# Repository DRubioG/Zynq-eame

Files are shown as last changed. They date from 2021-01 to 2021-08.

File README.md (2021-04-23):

# Introducción / Introduction

**[ES]** Este es el repositorio en GitHub del blog [soceame.wordpress.com](http://soceame.wordpress.com) en el que se colgará toda la información sobre cómo construir SoCs de Xilinx 

**[EN]** This is the GitHub's repository of the [soceame.wordpress.com](https://soceame.wordpress.com)'s blog where it will be uploaded all information about how to build Xilinx's SoCs

# Contenido / Content

- [Documentación/Documentation](/Documentacion): 

**[ES]** En esta carpeta se ubicarán los documentos que explican la construcción de los SoCs 

**[EN]** In this folder will be placed the documents which explaining how to build the SoCs

- [Zynq-eame_0](/Zynq-eame_0): ❗ No terminada / Unfinished ❗

**[ES]** Esta carpeta contiene los esquemáticos de la Zynq-eame_0 en pdf y en KiCad.

Esta placa está construida a partir de un XC7Z010-CLG400.

**[EN]** This folder contains the Zynq-eame_0' schematics in pdf and in KiCad.

This board is built from a XC7Z010-CLG400.

- [Zynq-eame_UltraScale_0](/Zynq-eame_UltraScale_0): ❗ Inicio / Started ❗

**[ES]** Esta carpeta contiene los esquemáticos de la Zynq-eame_UltraScale_0 en pdf y en KiCad.

Esta placa está construida a partir de un XCZU2CG-SBVA484.

**[EN]** This folder contains the Zynq-eame_UltraScale_0' schematics in pdf and in KiCad.

This board is built from a XCZU2CG-SBVA484.

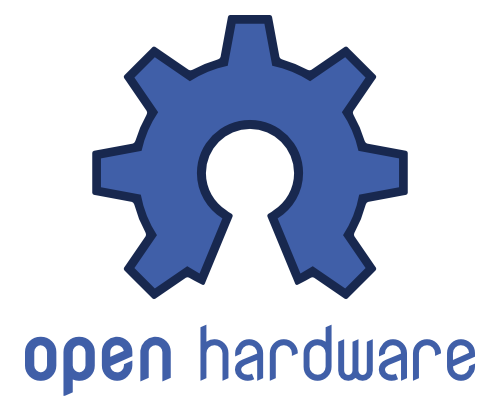
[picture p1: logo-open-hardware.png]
Open Hardware


**[ES]** Estos son proyectos Open Hardware 

**[EN]** These are Open Hardware projects

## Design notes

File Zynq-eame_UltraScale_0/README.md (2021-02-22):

# Zynq-eame UltraScale  0

## Descripción / Description

**[ES]** La Zynq-eame UltraScale 0 es un placa basada en un XCZU2CG de Xilinx de la familia de las Zynq UltraScale+.
Esta placa consta de:
- 1Gb de memoria ram DDR4 (512Mbx2)
- Salida HDMI 
- SD 3.0
- Comunicación USB
- USB-JTAG 
- Quad-SPI Flash Memory
- 5 switches programables (activos a nivel bajo)
- 5 botones programables (activos a nivel alto)
- 5 leds programable (activos a nivel alto)
- 3 bancos de pines: uno de 48 pines y otro de 26 pines programables por Hardware y uno de 38 pines de tipo MIO
- 2 bancos de pines de alimentación
- Encendido por switch
- Alimentación a 5V

**[EN]** Zynq-eame 0 is a XCZU2CG based board from the Zynq UltraScale+'s family from Xilinx.
This board consist of:
- 1Gb of DDR4 ram memory (512Mbx2)
- HDMI output
- SD 3.0
- USB communication
- USB-JTAG
- Quad-SPI Flash Memory
- 5 programmable switchs (low level active)
- 5 programmable buttons (high level active)
- 5 programmable led (high level active)
- 3 banks of pins: one with 48 pins and other with 26 pins hardware programmable and one with 38 MIO pins 
- 2 supply banks
- Turn-on by switch
- 5V of supply

## Esquemático / Schematic
👉 [Zynq-eame 0](Zynq-eame_UltraScale_0.pdf)

## Vivado
**[ES]** En este carpeta se ubicarán los documentos que harán la Zynq-eame 0 una [placa de Vivado](Vivado)

**[EN]** In this folder it will be placed the documents that will make Zynq-eame 0 a [Vivado's board](Vivado)

## Proyecto / Project
👉[Proyecto/Project](KiCad)

## Datasheet
👉[Datasheet](Datasheet)

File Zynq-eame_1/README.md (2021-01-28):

# Zynq-eame 0

## Descripción / Description

**[ES]** La Zynq-eame 0 es un placa basada en un XC7Z010 de Xilinx de la familia de las Zynq-7000.
Esta placa consta de:
- 512Mb de memoria ram DDR3
- Salida HDMI 
- SD
- Comunicación USB
- USB-JTAG 
- Quad-SPI Flash Memory
- 5 switches programables (activos a nivel bajo)
- 5 botones programables (activos a nivel alto)
- 5 leds programable (activos a nivel alto)
- 3 bancos de pines: uno de 48 pines y otro de 26 pines programables por Hardware y uno de 38 pines de tipo MIO
- 2 bancos de pines de alimentación
- Encendido por switch
- Alimentación a 5V

**[EN]** Zynq-eame 0 is a XC7Z010 based board from the Zynq-7000's family from Xilinx.
This board consist of:
- 512Mb of DDR3 ram memory
- HDMI output
- SD
- USB communication
- USB-JTAG
- Quad-SPI Flash Memory
- 5 programmable switchs (low level active)
- 5 programmable buttons (high level active)
- 5 programmable led (high level active)
- 3 banks of pins: one with 48 pins and other with 26 pins hardware programmable and one with 38 MIO pins 
- 2 supply banks
- Turn-on by switch
- 5V of supply

## Esquemático / Schematic
👉 [Zynq-eame 0](Zynq-eame_0.pdf)

## Vivado
**[ES]** En este carpeta se ubicarán los documentos que harán la Zynq-eame 0 una [placa de Vivado](Vivado)

**[EN]** In this folder it will be placed the documents that will make Zynq-eame 0 a [Vivado's board](Vivado)

## Proyecto / Project
👉[Proyecto/Project](KiCad)

## Datasheet
👉[Datasheet](Datasheets)

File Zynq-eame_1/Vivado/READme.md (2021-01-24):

# Descripción / Description 
[ES] En este carpeta se ubicarán los documentos que harán la Zynq-eame 0 una placa de Vivado

[EN] In this folder it will be placed the documents that will make Zynq-eame 0 a Vivado's board

## Documentos/Documents

- [Zynq-eame_XDC.xdc](Zynq-eame_XDC.xdc)

**[ES]** Este es el fichero XDC de la Zynq-eame 0

**[EN]** This is the Zynq-eame 0's XDC file

- [Zynq-eame](Zynq-eame)

**[ES]** Esta carpeta contiene todos los ficheros que hacen la placa reconocible en Vivado. Pegar en el directorio: *..\Xilinx\Vivado\<version de Vivado>\data\boards\board_files* . Con esta carpeta se pueden usar los bloques IP como AXI_GPIO, Microblaze_msc, iomodule y clock_wiz con los pines de la Zynq-eame.

**[EN]** This folder contains every file that makes reconocible the board in Vivado. Paste in the path: *..\Xilinx\Vivado\<version of Vivado>\data\boards\board_files*  . With this folder you can use  IP blocks as AXI_GPIO, Microblaze_msc, iomodule and closk_wiz with the pins of Zynq-eame.

- [Zynq-eame.tcl](Zynq-eame.tcl)

**[ES]** Pega este archivo en el siguiente directorio: *..\Xilinx\Vivado\<version de vivado>\data\ip\xilinx\processing_system7_v5_5\preset* . Este fichero es la preconfiguración de la Zynq-eame 0 con toda la configuración del Zynq. **Este archivo lo carga la configuración anterior**

**[EN]** Paste this file in this path: *..\Xilinx\Vivado\<version of vivado>\data\ip\xilinx\processing_system7_v5_5\preset* . This file is the preconfiguration of the Zynq-eame 0 with all configuration of the Zynq. **This file is precharged by the previous configuration**

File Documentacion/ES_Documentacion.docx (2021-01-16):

XD

Soc-eame | soceame.wordpress.com

diseño de un SoC basado en Zynq-7000

# Introducción

En este documento se detallará de la forma más extensa y detallada la forma de crear un SoC basado en un Zynq-7000 de Xilinx, detallando dónde encontrar los documentos y la información necesaria para la construcción de uno, además también se incluye cómo se configura en Vivado para que reconozca la nueva placa como una placa preconfigurada.

Al final del documento se incluye un ejemplo de cómo construir un SoC basado en un núcleo xc7z010-clg400 [este ejemplo se corresponde con la construcción de una Zynq-eame 0]

Este documento ha sido desarrollado por el blog https://soceame.wordpress.com/ Para cualquier aporte o mejora soceame@gmail.com.

Y para cualquier aportación económica para futuros proyectos http://paypal.me/soceame

# ¿Qué es un SoC?

Un SoC es la combinación de la electrónica de una FPGA con un microprocesador embebido en un chip.

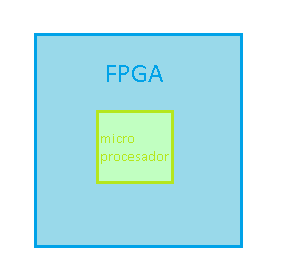
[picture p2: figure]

## Diferencia entre un SoC, un microcontrolador y una FPGA

| SoC | Microcontrolador | FPGA
Microprocesador | ✔ | ✔ | ❌ (pero se le puede configurar un soft-core)*
Hardware programable | ✔ | ❌ | ✔
Lenguajes de programación | HDLs y lenguajes de medio-bajo nivel | Lenguajes de bajo-medio nivel: C, C++ | HDLs**: VHDL, Verilog
Precio del chip | Medio-alto (de la familia Zynq-7000, de 35€ hasta 20.000€) | Bajo | Bajo-Medio

* Un soft-core en un microprocesador creado usando las puertas lógicas internas del chip

** Los lenguajes HDL son “lenguajes de descripción de hardware” por lo que con ellos se puede programar el hardware

# Comienzo

Lo primero que hay que hacer para construir una Zynq-7000 es saber los tipos de Zynq que hay.

Para ello se recurre al Product Selection Guide (https://www.xilinx.com/support/documentation/selection-guides/zynq-7000-product-selection-guide.pdf) de Xilinx para la Zynq-7000. En él se encuentra una tabla como la siguiente en la que se desglosa qué contienen internamente los diferentes tipos de Zynq.

Como se puede ver hay una parte de la familia que solo tiene un microprocesador, mientras el resto tiene dos microprocesadores dentro con diferentes velocidades.

Otro factor condicionante a la hora de elegir un chip son las puertas lógicas internas, para ello es conveniente elegir más puertas lógicas de las que se van a necesitar para evitar problemas de falta de celdas.

## Número de pines

Para construir un SoC también hay que tener en cuenta el número de pines que va a tener la salida para poder crear el símbolo en el programa de diseño. En el mismo documento de antes existe la tabla que determina los pines que puede tener cada chip

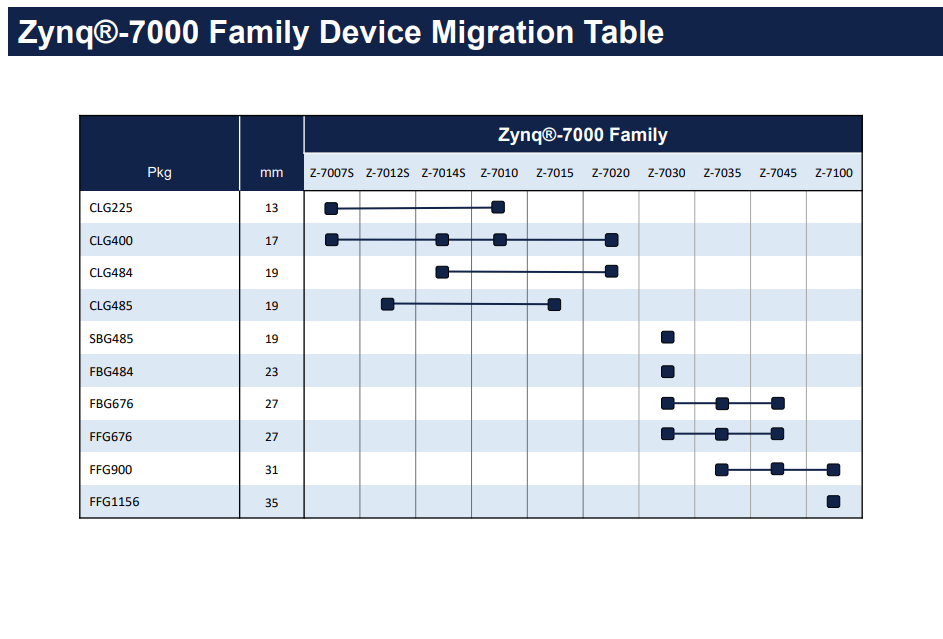
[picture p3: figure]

Según la tabla si se quiere construir un SoC con el Z-7007S se puede elegir el encapsulado CLG225 y el CLG400, se diferencian en que el encapsulado CLG225 tiene 225 pines en una matriz de 15 filas x 15 columnas, y el CLG400 igual pero con 400 pines.

A partir de ahora se va a documentar la construcción de SoC.

Para una mayor documentación sobre la familia Zynq-7000 👇

https://www.xilinx.com/support/documentation/data_sheets/ds190-Zynq-7000-Overview.pdf

# Pinout

Para localizar la configuración del número y el tipo de pines se tiene que recurrir al documento Packaging and Pinout (https://www.xilinx.com/support/documentation/user_guides/ug865-Zynq-7000-Pkg-Pinout.pdf).

En este documento figuran los nombres de los pines, la definición de los pines y las huellas de los diferentes encapsulados.

## Nombres de los pines

❗❗ Esto es extremadamente importante porque NO figuran implícitamente en el documento, figuran como un enlace a otros documentos❗❗

En la página 27 del documento figuran los enlaces a los respectivos documentos en función del chip y del encapsulado

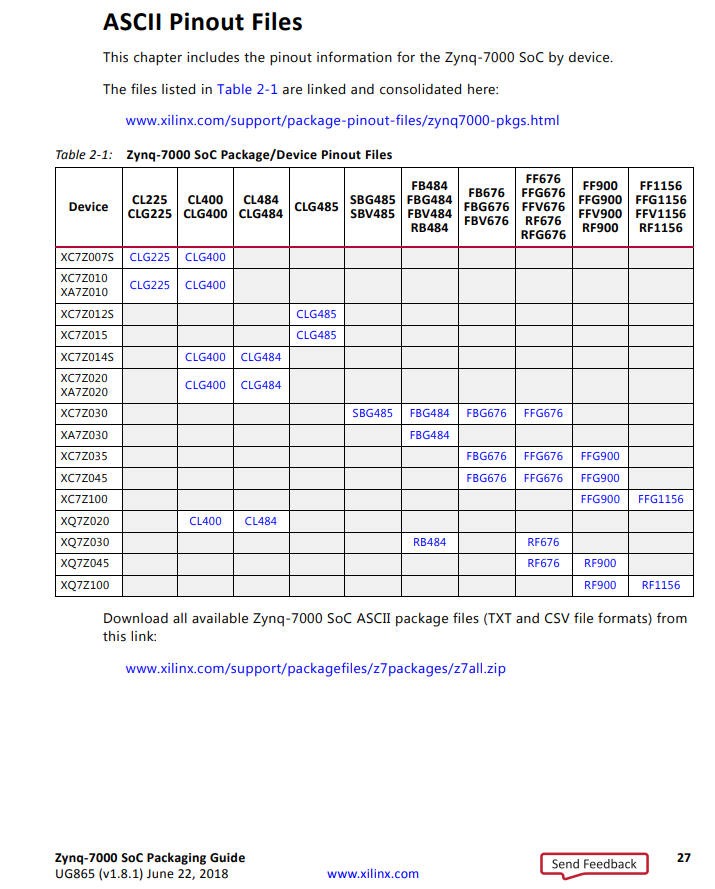
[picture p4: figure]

Estos enlaces llevan a páginas como la siguiente, en la que los pines están clasificados en bancos.

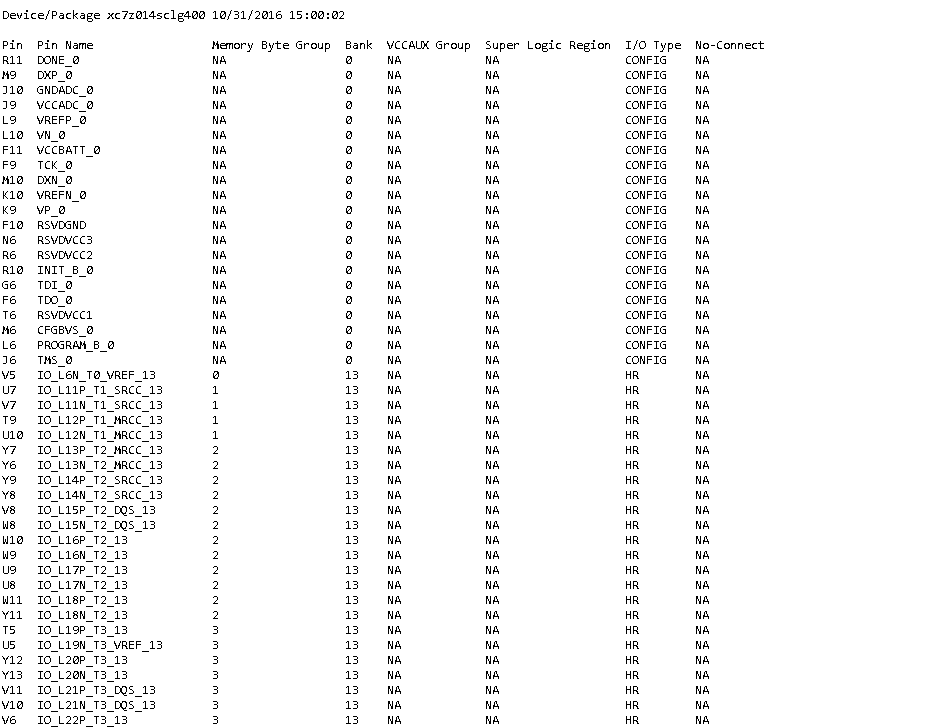
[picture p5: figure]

Los campos importantes son:

En la primera columna figura el número del pin*(este número es importante porque luego se utilizará para generar el XDC).

La segunda columna se corresponde con el nombre del pin, este nombre es importante para saber cuales son los bits de mayor o menor peso o la dedicación que tiene

La cuarta columna se corresponde con el banco de pines al que pertenecen los pines( esta división por bancos se puede utilizar para crear el símbolo del componente)

La octava columna se corresponde con el tipo de pin, CONFIG para configuración, HR para configurar por hardware, MIO para pines de tipo MIO, DDR pines para la memoria Ram y NA para alimentaciones y masas.

*el número del pin se corresponde con la numeración de los encapsulados en forma de matriz cuadrada, las columnas están ordenadas por números, y las filas por letras. Por ejemplo, el formato CLG25 tiene 5 filas y 5 columnas, por lo que la primera fila empieza por el pin A1 y acaba por el pin A5, la siguiente fila por el B1 – B5, y así hasta la última fila, E1-E5.

## Definición de los pines.

De la página 12 en adelante del documento figura la definición de los pines.

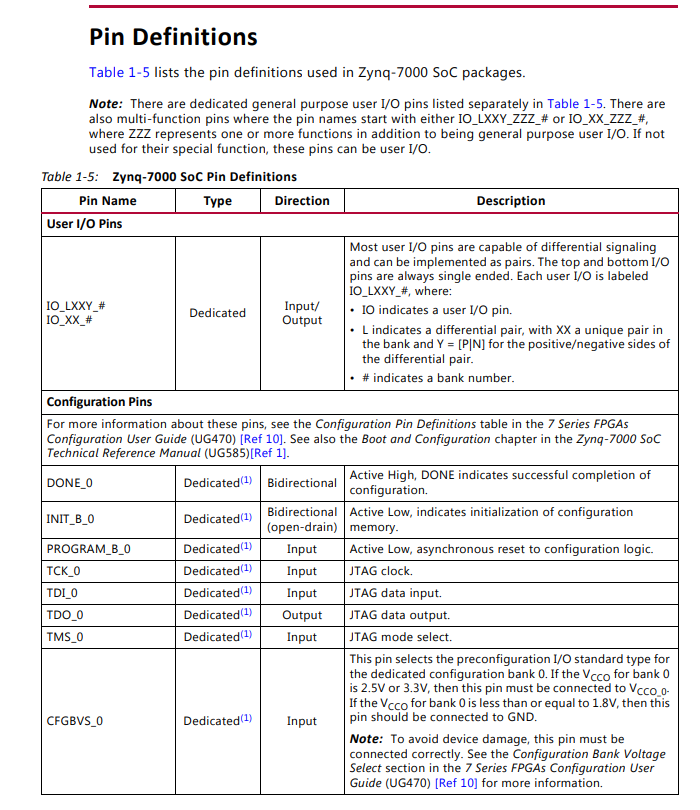
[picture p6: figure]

# Huellas de los encapsulados

Al final del documento figuran las estructuras de los pines en chip y las huellas

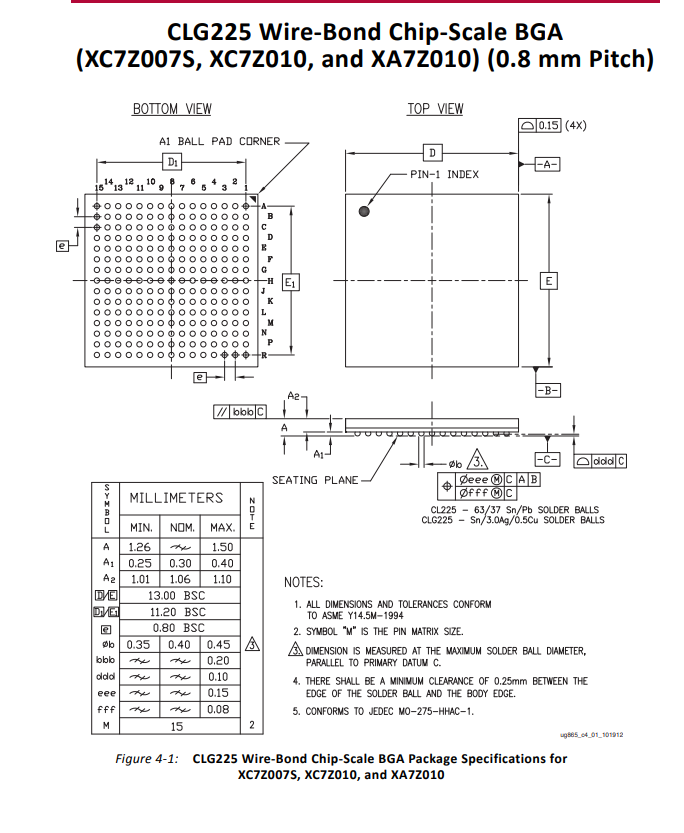
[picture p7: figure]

**Estas huellas con del chip que se va a soldar, NO las huellas que se tienen que hacer en la PCB, estas últimas son las simétricas con el eje vertical. La huella que se tiene que fabricar en la PCB tiene que tener el pin A1 en la parte superior izquierda.

# Ejemplo

## Introducción

Debido a que explicar cómo construir un SoC es complejo ahora se va a explicar con un ejemplo.

Se va a construir una Zynq-eame 0 que está basada en un XC7Z010-CLG400.

Zynq-eame es una placa creada para Open Hardware por el blog soceame.wordpress.com utilizando KiCad(software Open Source)

## Documentación

Un XC7Z010 consta de las características que nos da la tabla.

## Pinout

Para el Pinout se recurre a la tabla

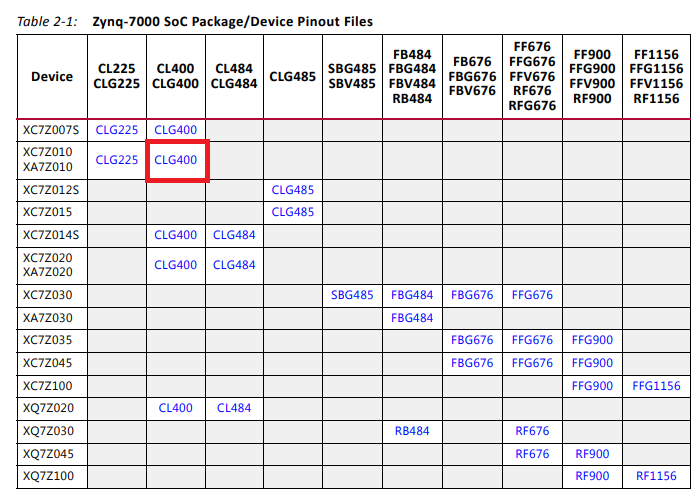
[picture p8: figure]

Que nos lleva a la página (https://www.xilinx.com/support/packagefiles/z7packages/xc7z010clg400pkg.txt) con los pines se parados por bancos. A partir de esta separación por pines se pueden hacer los símbolos en el programa de diseño de PCBs.

## Símbolo.

Para hacer los símbolos se va a recurrir a la separación por bancos de la que se ha hablado anteriormente.

- Bank 0

Este banco está reservado para las referencias, por ejemplo, la tensión del ADC o la referencia de temperatura

  - Pinout
  - Símbolo

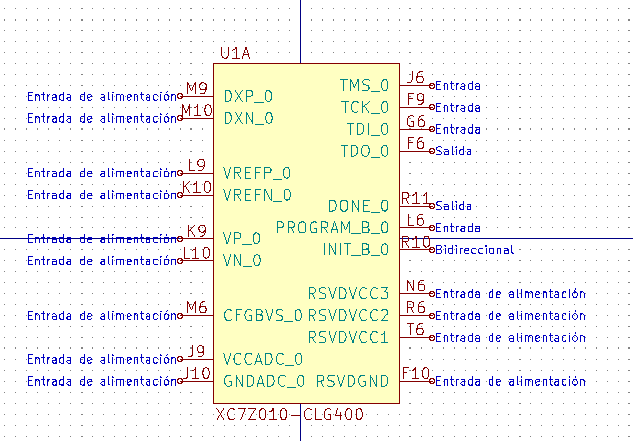
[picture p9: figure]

- Unconnected

Estos pines en el XC7Z010 no están conectados pero en otros formatos sí que lo pueden estar

  - Pinout
  - Símbolo

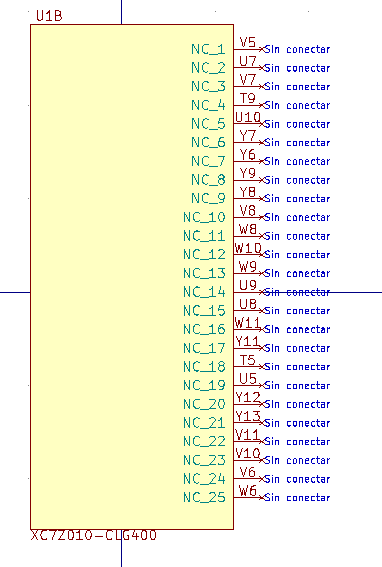
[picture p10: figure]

- Bank 34

Estos pines son configurables como entrada y salida por hardware. Entre los pines de este banco hay pines que pueden tener otro tipo de configuración.

  - Pinout
  - Símbolo

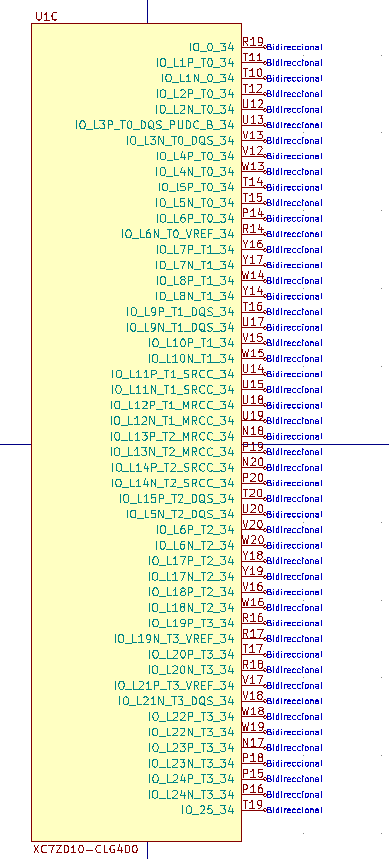
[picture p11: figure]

- Bank 35

Estos pines son configurables como entrada y salida por hardware. Entre los pines de este banco hay pines que pueden tener otro tipo de configuración.

  - Pinout
  - Símbolo

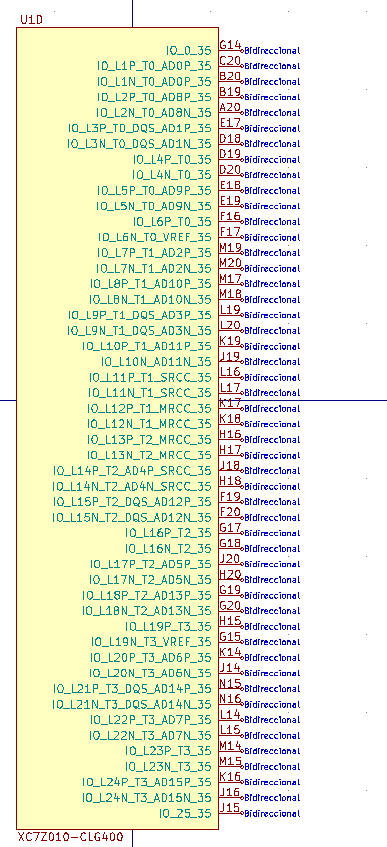
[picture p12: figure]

- Bank 500 & 501

Estos bancos están destinados para los pines de tipo MIO (Multiple IO)

  - Pinout
  - Símbolo

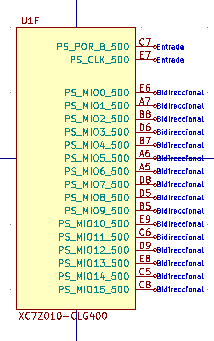
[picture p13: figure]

- Bank 502

Este banco está destinado únicamente a la memoria Ram, 15 bits de Address y 32 bits de Datos

  - Pinout

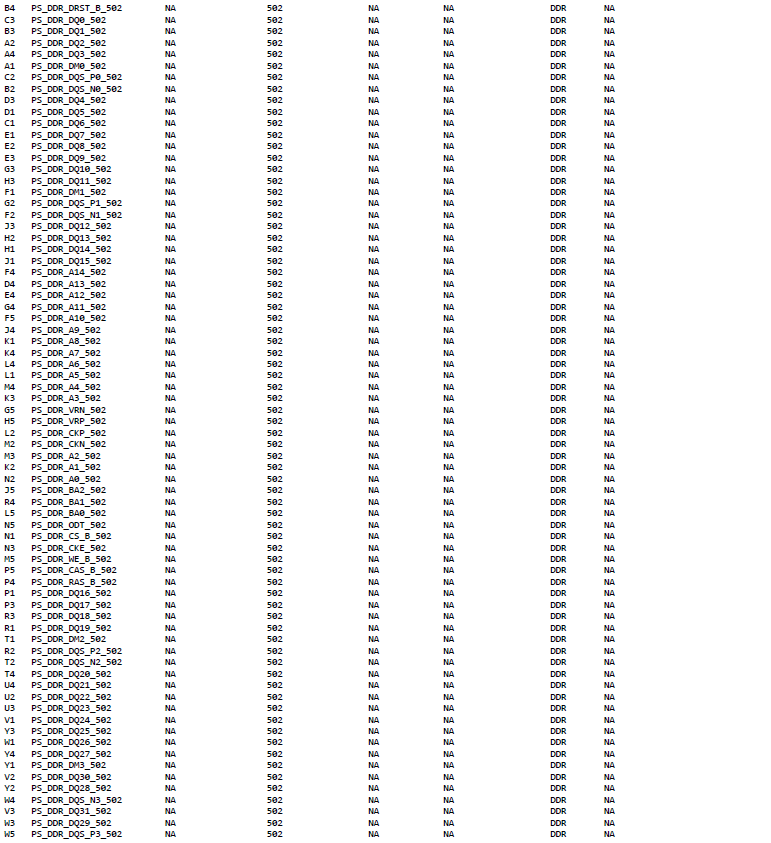
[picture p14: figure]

👆estos dos últimos pines están al final del documento

  - Símbolo
- Bank GND

Este banco está destinado únicamente a masas

  - Pinout

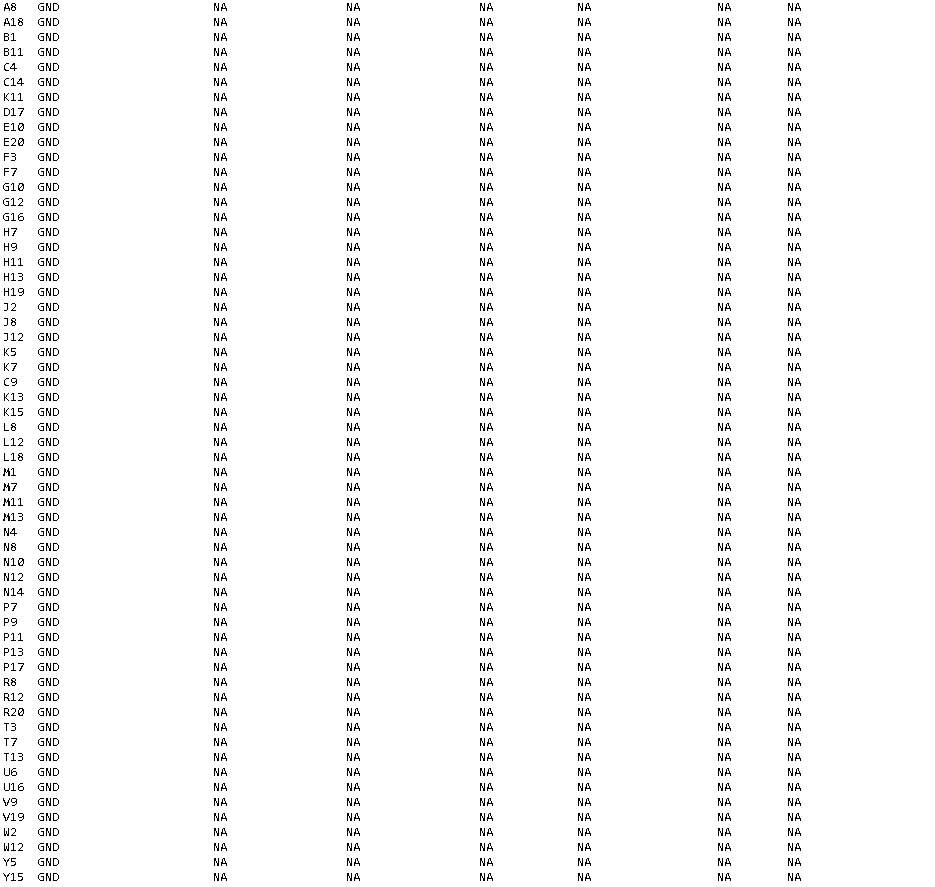
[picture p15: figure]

  - Símbolo
- Bank VCC

Este banco está destinado únicamente a las diferentes alimentaciones del sistema.

  - Pinout

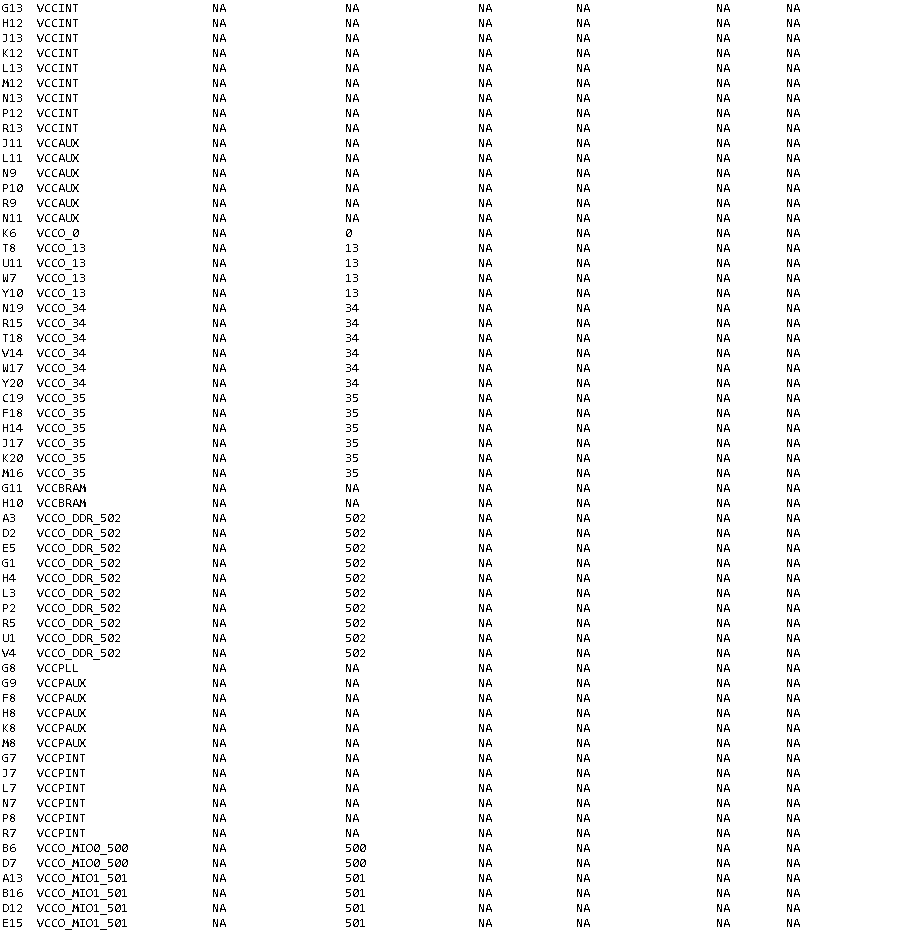
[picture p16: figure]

  - Símbolo

# Conexión

Para la conexión de va a desglosar para cada pin cómo debería estar conectado.

- Bank 0

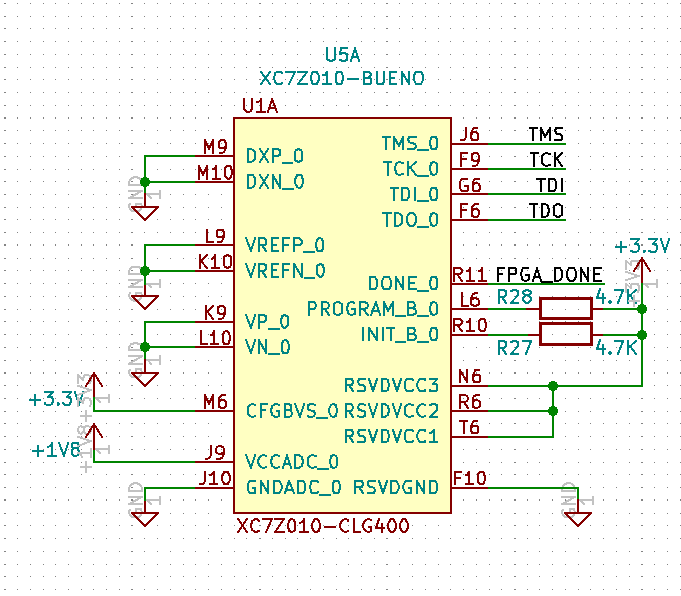
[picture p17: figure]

DXP_0 y DXN_0 a masa porque no se va a conectar un diodo para el sensado de la temperatura.

VREFP_0, VREFN_0, VP_0 y VN_0 a masa porque no se va a conectar un ADC.

CFBVS_0 a 3.3V para preconfigurar los pines

VCCADC_0 es la tensión de alimentación del XADC, tiene que estar a 1.8V

GNDADC_0 es la masa del XADC, se conecta a la masa general porque no se va a utilizar el ADC.

RSVDVCC[3:1] tienen que ir a la tensión Vcco_0, en el caso de la Zynq-eame 0 a 3V3.

INIT_B_0 indica la inicialización de la configuración de la memoria, se activa a nivel bajo.

PROGRAM_B_0 reset asíncrono activo a nivel bajo. Se conecta a 3V3 porque no se resetea la placa.

DONE_0 indica que la configuración se ha completado, activo a nivel alto. En la Zynq-eame se conecta a un diodo LED para indicar si se ha cargado la placa.

TMS_0, TCK_0, TDI_0 y TDO_0 son los pines del JTAG, estos pines pueden ir a un cable depurador o a un chip que permita cargar el programa por USB. En la Zynq-eame se utiliza el FT2232H, se necesita de una EEPROM y un oscilador de 12MHz pero elimina la necesidad de un cable depurador.

- Bank Unconnected
- Bank 34

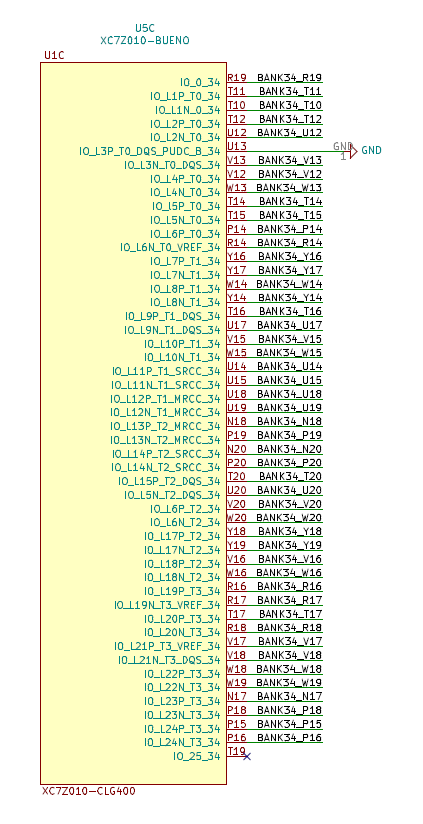
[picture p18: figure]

Todos lo pines IO son pines que se pueden configurar por Hardware y algunos de ellos pueden adquirir otras configuraciones.

Los pines IO_Ln[P/N] son pines diferenciales utilizados por el XADC.

El pin PUBC_B es un pin que activa las resistencias de pull-up del sistema después del arranque y durante la configuración. Activa a nivel bajo, tiene que ir directamente a GND o a VCCO_34

SRCC y MRCC estos pines permiten que un reloj funcione en varias regiones(MRCC) o en solo una (SRCC). Estos pines tienen interés en las FPGAs para conectar el oscilador de la frecuencia a ellas. La Zynq-eame no lleva conectado un reloj a un pin MRCC por eso no puede ser utilizada como una FPGA sin activar el reloj interno del Zynq.

En la Zynq-eame 0 todo el banco va a pines de salida, menos el pin PUBC_B que va a masa y el pin T19 que no se conecta porque no tiene un pin de salida.

- Bank 35

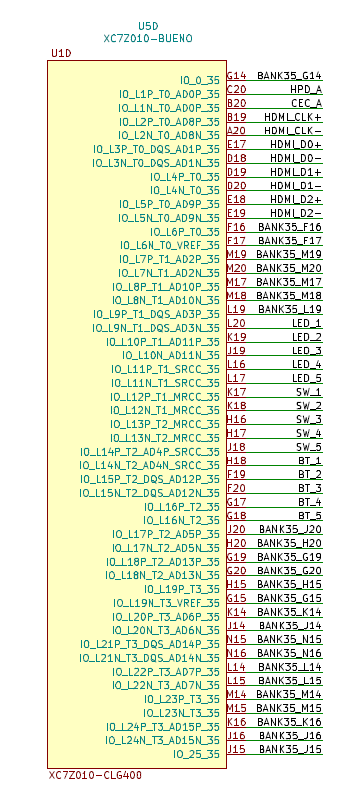
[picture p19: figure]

Pasa igual que en el banco 34, hay pines con múltiples funciones.

Este banco se utiliza entero.

Se conectan los pines HDMI a los pines elegidos, éstos van a un TPD12S016 que va conectado al HDMI hembra

Les pines que se van a utilizar para los leds llevan un transistor para funcionar.

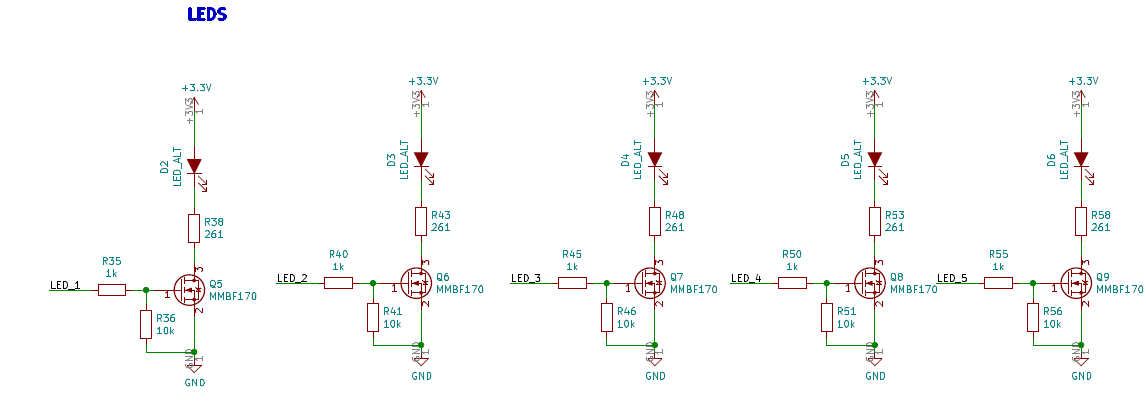
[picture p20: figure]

Los pines que van a los switches son activos a nivel bajo.

Los pines que van a los botones son activos a nivel alto.

Y el resto de los pines va a pines de salida.

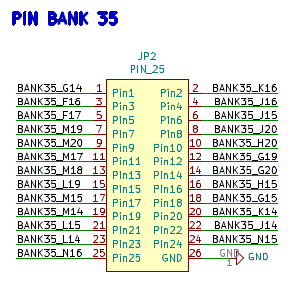
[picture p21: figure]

- Bank 500 & 501

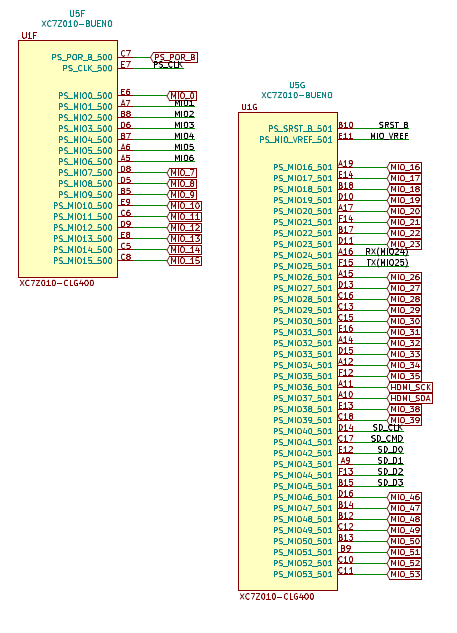
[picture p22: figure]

Banco 500:

PS_POR_B utiliza para mantener un reset al arranque del sistema, el sistema que se utiliza es un supervisor que mantiene el sistema reseteaso. Para eso se utiliza el dispositivo que propone Xilinx (https://www.xilinx.com/Attachment/AR65240_-_Example_PS_POR_B_Supervisor_Circuit.pdf), un TPS3106K33DBV, que mantiene el reset durante 130ms[según el datasheet (https://www.ti.com/lit/ds/symlink/tps3106.pdf?ts=1610541218328)].

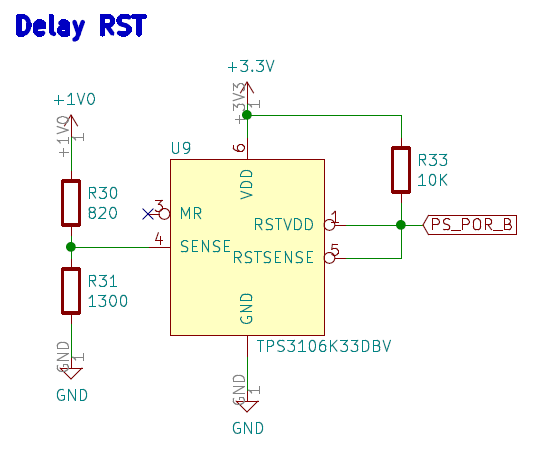
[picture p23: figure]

PS_CLK este es el reloj del sistema y tiene que ir conectado a un oscilador entre 30 y 60MHz, en la Zynq-eame se conecta a 33.333MHz.

Los pines MIO se utilizan para pines de comunicación multiplexada.

Por eso la multiplexación de los pines 1 al 6 es la de una QUAD-SPI FLASH MEMORY

El resto de pines va a pines de salida con el resto de pines del bank MIO 501

Bank 501:

PS_SRST este pin fuerza el reseteo del sistema, activo a nivel bajo. En una Zynq-eame se conecta a un pulsador.

MIO_VREF proporciona de una tensión de referencia para RGMII (Fast Ethernet) si no se usa se puede dejar al aire. Si se conecta una interfaz RGMII se tiene que usar un divisor de tensión de 1/2, por lo que si la interfaz es de 1.8V a la entrada tiene que haber 0.9V. La Zynq-eame 0 no tiene conexión a Fast Ethernet por lo que se deja al aire.

Lo pines mio 24 y 25 son pines MIO que tienen la posibilidad de configurar la UART. Estos pines son lo que se usan para la comunicación USB.

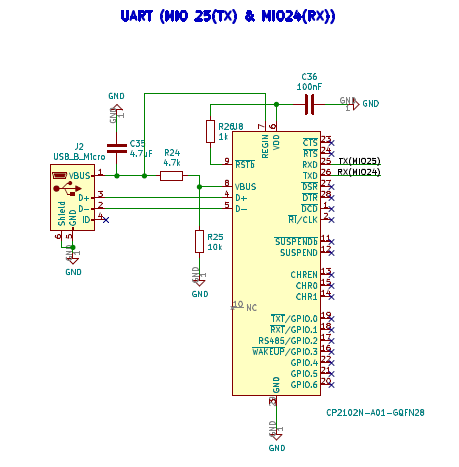
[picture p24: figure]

Los pines 40-45 son pines que permiten la conexión de una memoria SD.

El resto de los pines va conectado a pines externos

La referencia para la conexión de los pines MIO es la siguiente tabla.

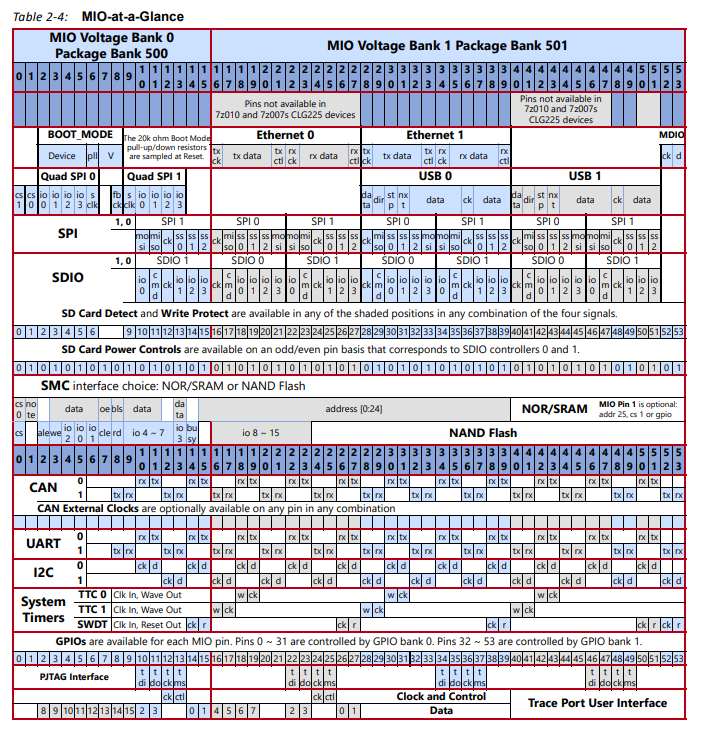
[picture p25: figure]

2 soceame.wordpress.com

Diseño de un SoC basado en una Zynq-7000

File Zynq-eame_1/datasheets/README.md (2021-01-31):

# Datasheets

## Zynq-7000
[XC7Z020 pinout](XC7Z020-CLG400_pinout.pdf)

[Zynq-7000 pinout](ug865-Zynq-7000-Pkg-Pinout.pdf)

## DDR
[Ram memory](MT41K256M16HA-125_E.pdf)

# Quad-SPI Flash Memory
[S25FL128S](S25FL128S.pdf)

## RST delay
[Xilinx example](AR65240_-_Example_PS_POR_B_Supervisor_Circuit.pdf)

[TPS3106](tps3106.pdf)

## Oscillator
[ASE-33.333MHz-LC-T](ASE-33.333MHz-LC-T.pdf)

## DC-DC 
[DC-DC](tps563201.pdf)

## HDMI 
[HDMI](tpd12s016.pdf)

## USB-JTAG
[FT2232H](DS_FT2232H.pdf)

[EEPROM](96C46.pdf)

## USB COMM
[USB COMM](an976-cp2102-3-4-9-to-cp2102n-porting-guide.pdf)

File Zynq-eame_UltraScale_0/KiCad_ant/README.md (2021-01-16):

# FPGA_propia
 En este repositorio se subirán los ficheros que permitirán crear una FPGA basada en Zynq-7000

Todo el desarrollo está hecho con KiCad (software libre) para que cualquiera pueda replicarla o mejorarla a su gusto con los ficheros que se van a publicar

## Libreria
El fichero tiene una librería llamada 'Zynq-7000' en la que está el symbol de un XC7Z010 del cual se implementará la versión CLG400 (400 pines en formato de soldadura BGA) 
## XC7Z010-BUENO
El símbolo consta de 9 partes, de las que se va a describir su selección a continuación
### - _Símbolo A_
diseno_A

En este símbolo se reflejan los pines de referencia, además de los pines de depuración TMS, TCK, TDI y TDO. Estos pines pueden necesitar de un cable depurar para cargar el programa o de un USB OTG, que permita evitar tener que usar un cable depurador.

### - _Símbolo B_
diseno_B

En este símbolo se reflejan los pines que no tienen conexión

### - _Símbolo c_
diseno_C

En este símbolo se reflejan los pines de entrada/salida que se podrán configurar como se quiera

### - _Símbolo D_
diseno_D

En este símbolo se reflejan los pines de entrada/salida que se podrán configurar como se quiera

### - _Símbolo E_
diseno_E

En este símbolo se reflejan los pines que van a ir a la/las memoria ram. A los pines de la ram se pueden unir varias memorias para aumentar su tamaño.

### - _Símbolo F_
diseno_F

En este símbolo se reflejan los pines MIO

### - _Símbolo G_
diseno_G

En este símbolo se reflejan los pines MIO continuación de los anteriores

### - _Símbolo H_
diseno_F

En este símbolo se reflejan las alimentaciones de cada parte del integrado. Hay que tener en cuenta que cada parte tiene una alimentación distinta, la VCCO_BRAM y los VCCO_PINT de 1V, los VCCO_MIO 3.3V, los VCCO_DDR de 1.35V y los VCCAUX y los VCCPAUX de 1.8V

### - _Símbolo I_
diseno_I

En este símbolo se reflejan las masas de todo el integrado. Todas las masas van unidas a mismo punto.

### - *Formato del integrado*
CLG400

En esta imagen se refleja como es el integrado CLG400 de 400 pines(20x20) para BGA

*** Toda la documentación del frabicante se puede obtener del siguiente enlace: ***
Documentación para el empaquetado: https://www.xilinx.com/support/documentation/user_guides/ug865-Zynq-7000-Pkg-Pinout.pdf
Documentación de los pines: https://www.xilinx.com/support/packagefiles/z7packages/xc7z010clg400pkg.txt

## Memoria RAM
Para la memoria ram se utiliza una MT4K256M16TW-107:P
### Datasheet
http://www.farnell.com/datasheets/3151560.pdf
### Símbolo
El símbolo utilizado es el siguiente
Memoria Ram
### Huella
La huella de la memoria ram consta de una matriz de 6x16 que está fragmetada en dos partes separadas por una zona en la que van 3 columnas de pines vacías.
Huella Memoria Ram

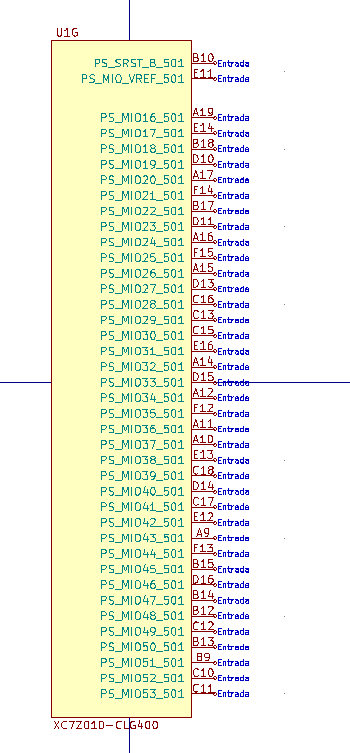
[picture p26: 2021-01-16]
Zynq-eame_1/KiCad/imagenes/XC7Z010-U1G.PNG

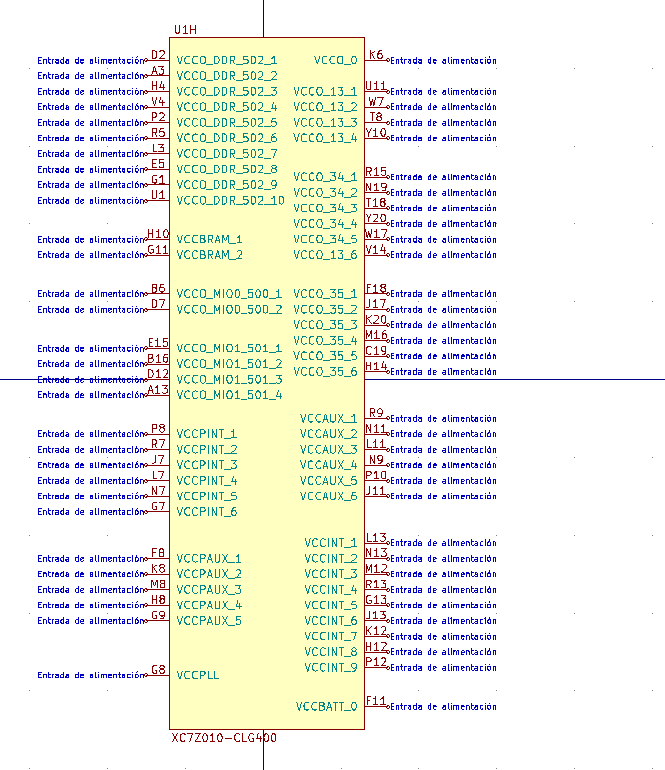
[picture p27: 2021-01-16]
Zynq-eame_1/KiCad/imagenes/XC7Z010-U1H.PNG

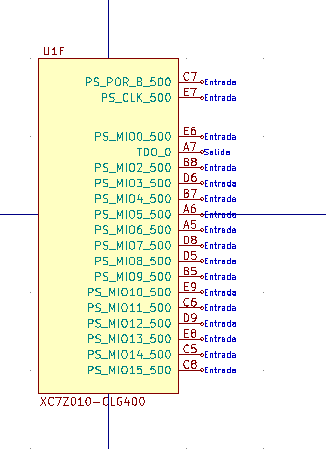
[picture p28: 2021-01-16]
Zynq-eame_1/KiCad/imagenes/XC7Z010-U1F.PNG

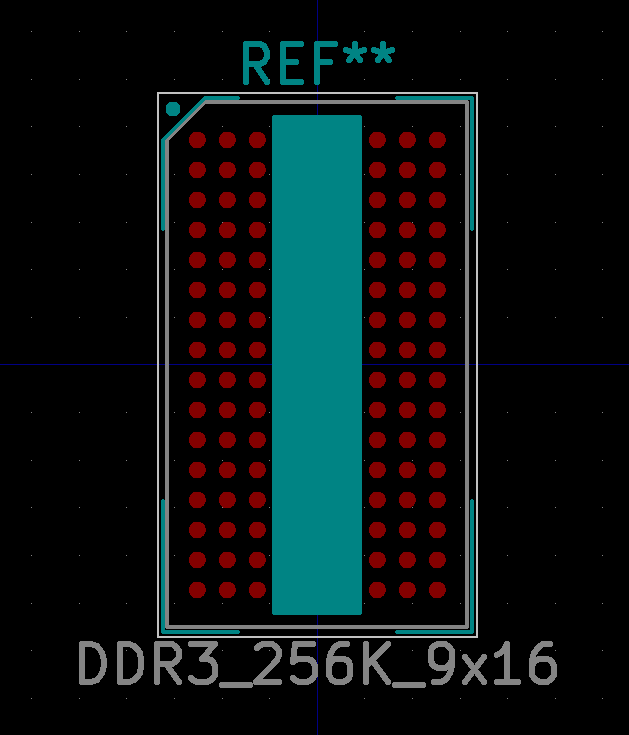
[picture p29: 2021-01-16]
Zynq-eame_1/KiCad/imagenes/TPS563201_huella.PNG

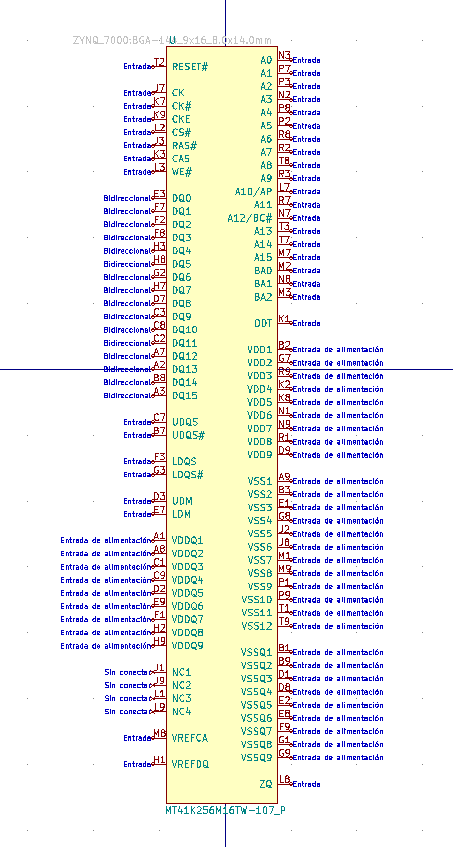
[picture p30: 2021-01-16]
Zynq-eame_1/KiCad/imagenes/TPS563201.PNG

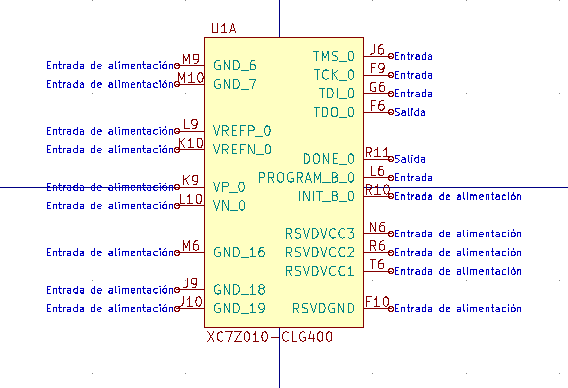
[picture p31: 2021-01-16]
Zynq-eame_1/KiCad/imagenes/XC7Z010-U1A.PNG

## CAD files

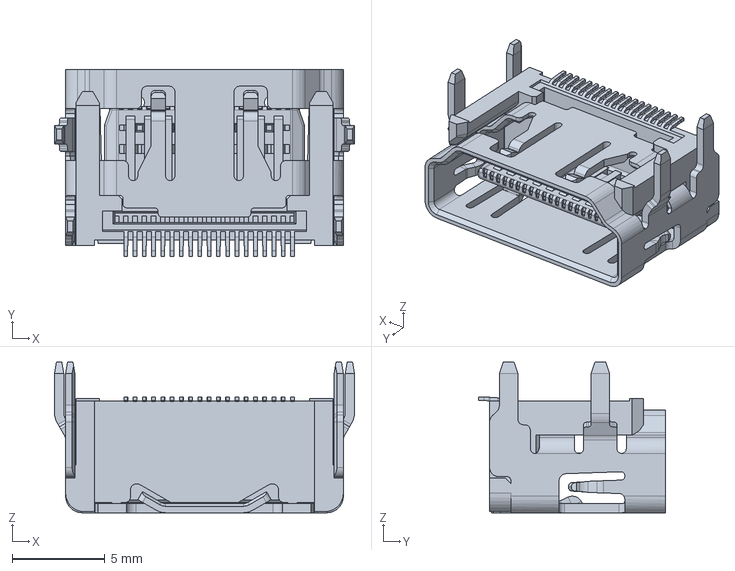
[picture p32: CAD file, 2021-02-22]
Zynq-eame_0/KiCad/10029449-111RLF.stp
16.2 x 10.1 x 8.13 mm

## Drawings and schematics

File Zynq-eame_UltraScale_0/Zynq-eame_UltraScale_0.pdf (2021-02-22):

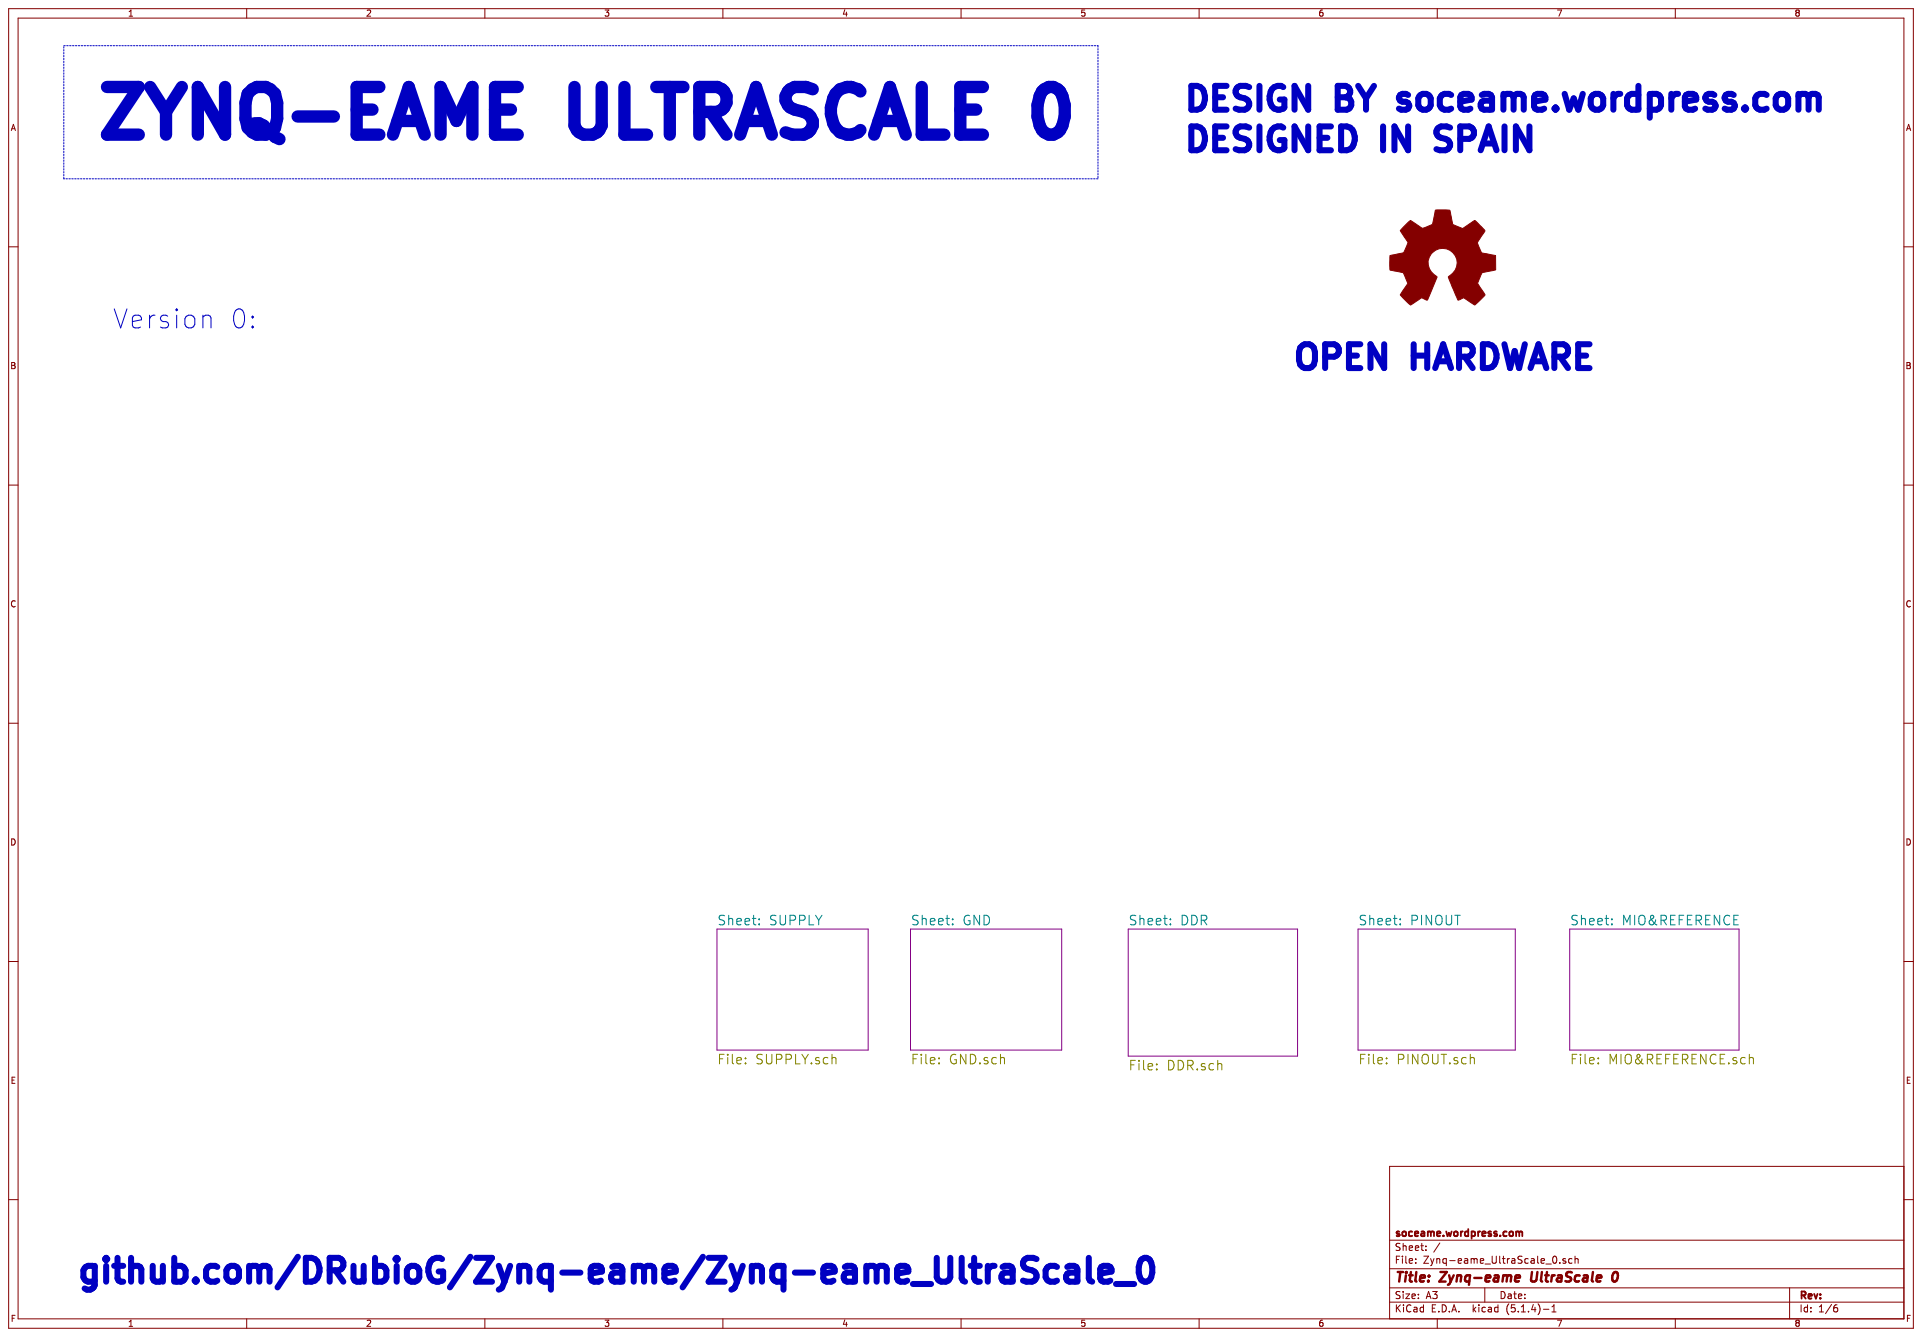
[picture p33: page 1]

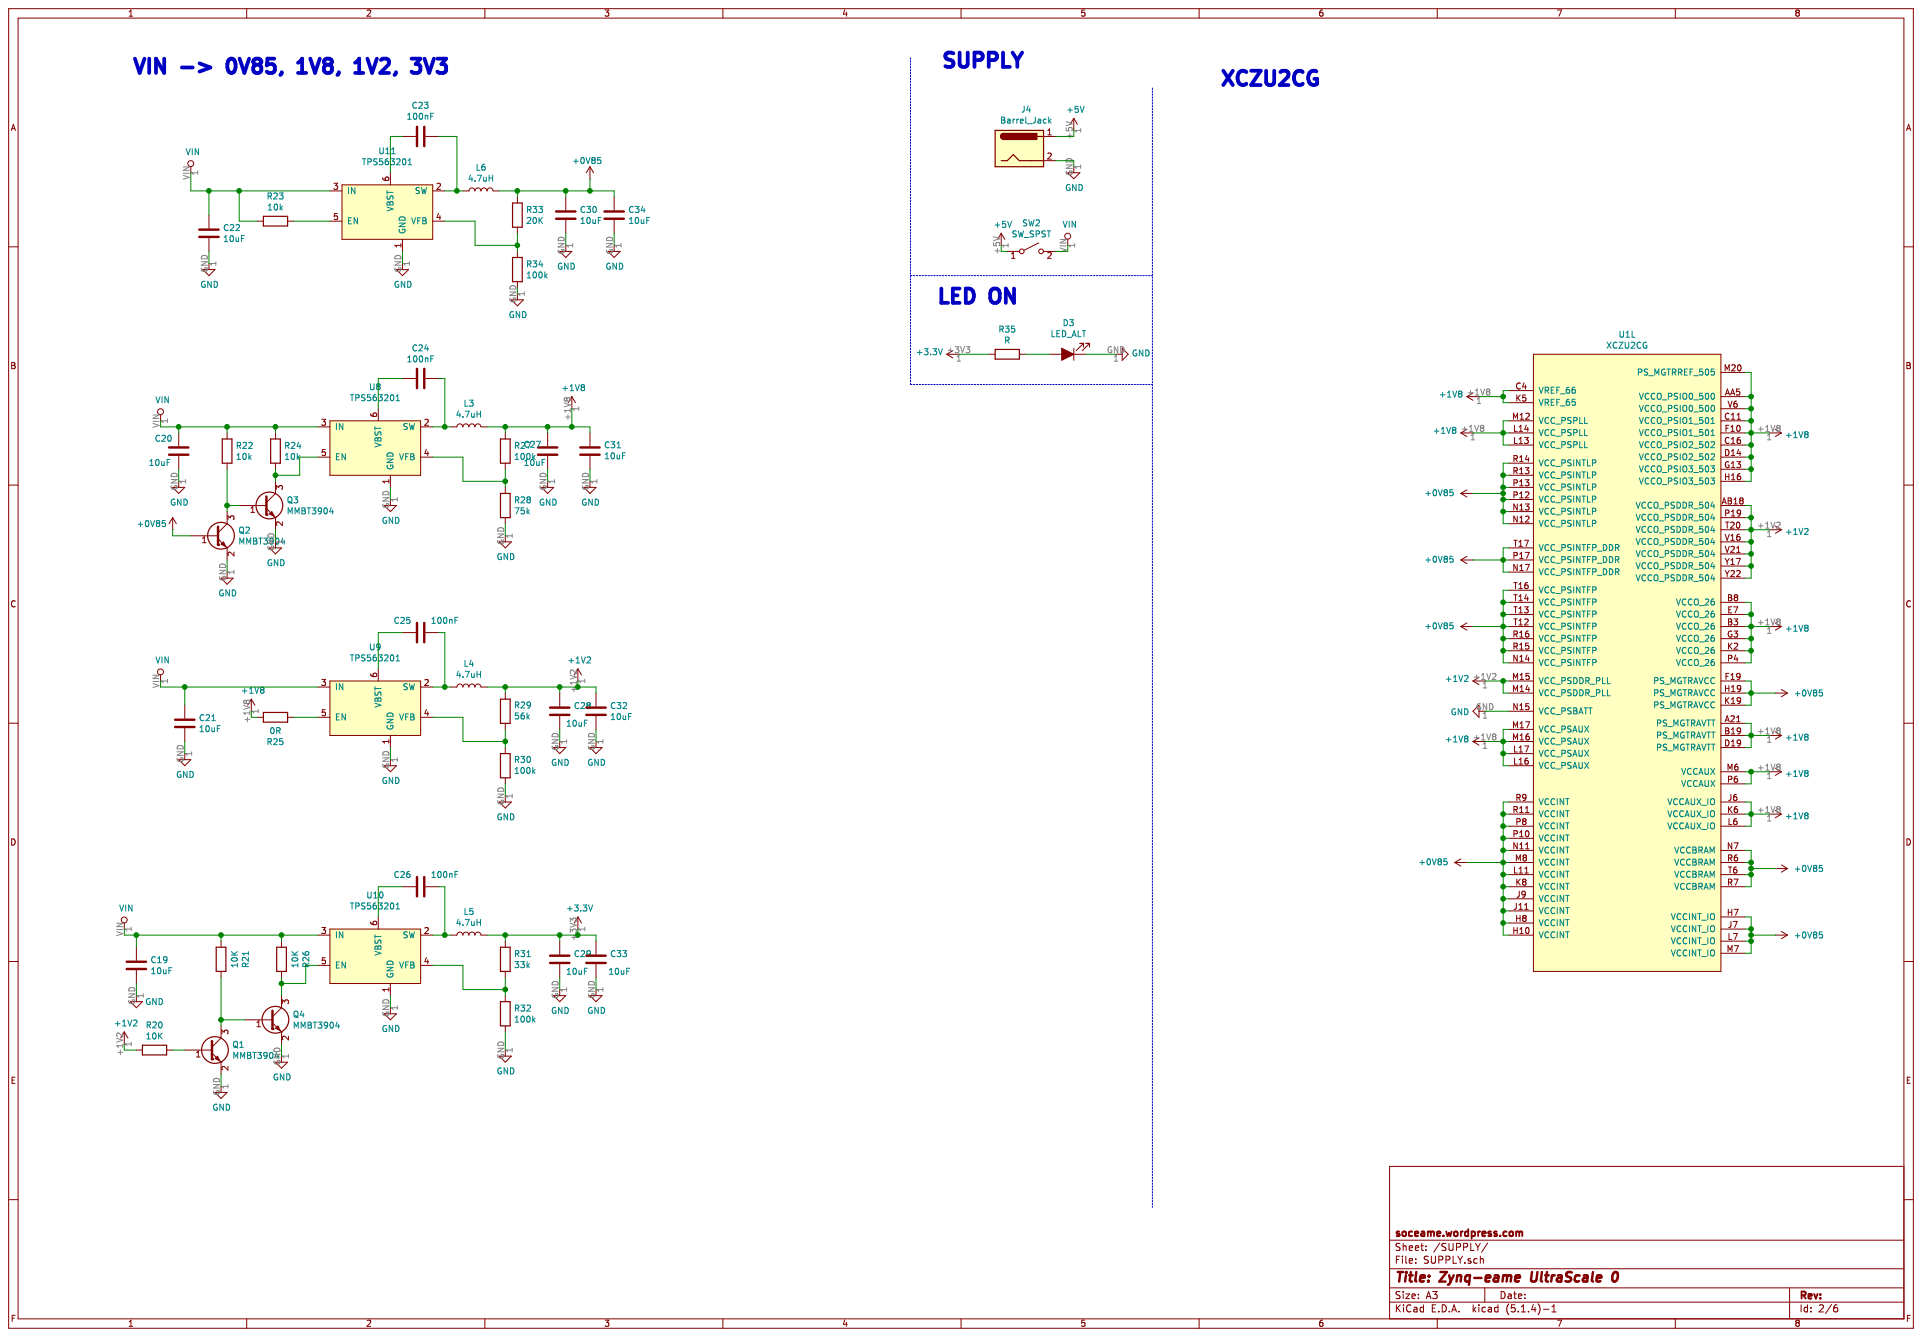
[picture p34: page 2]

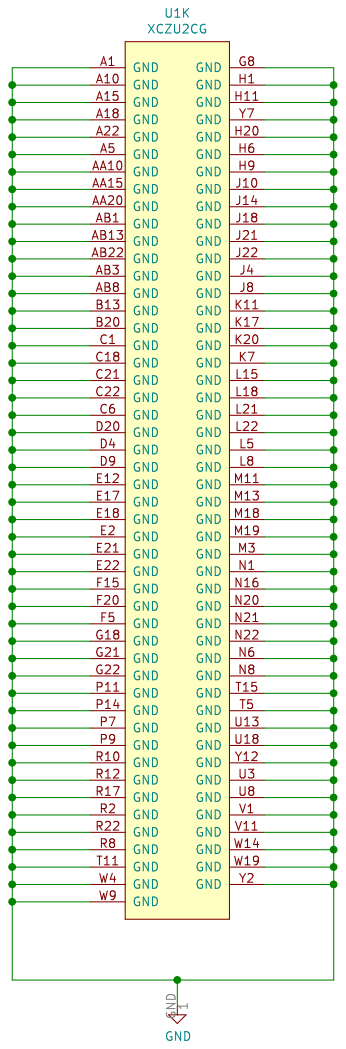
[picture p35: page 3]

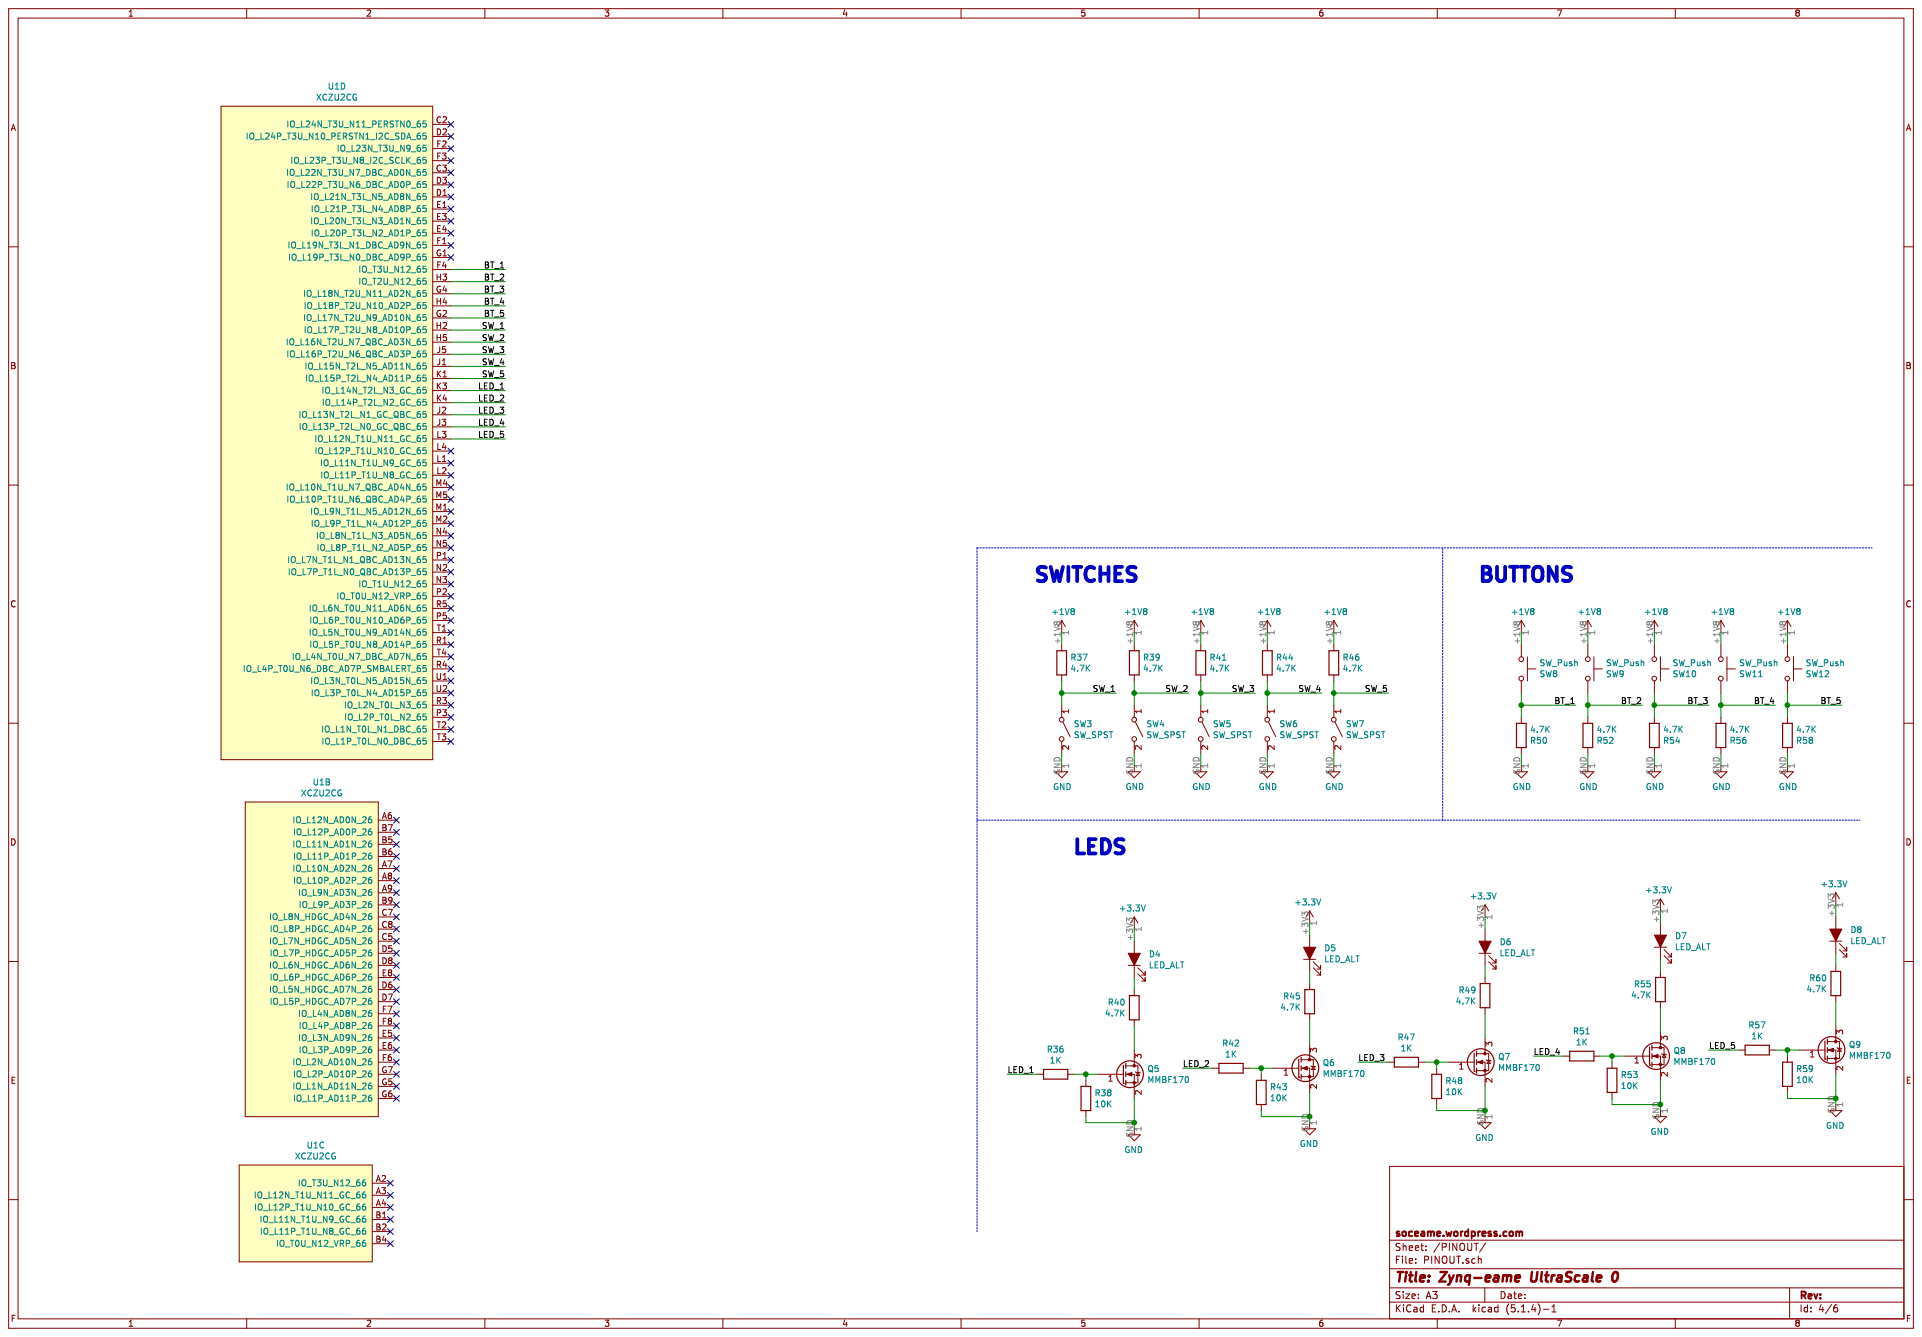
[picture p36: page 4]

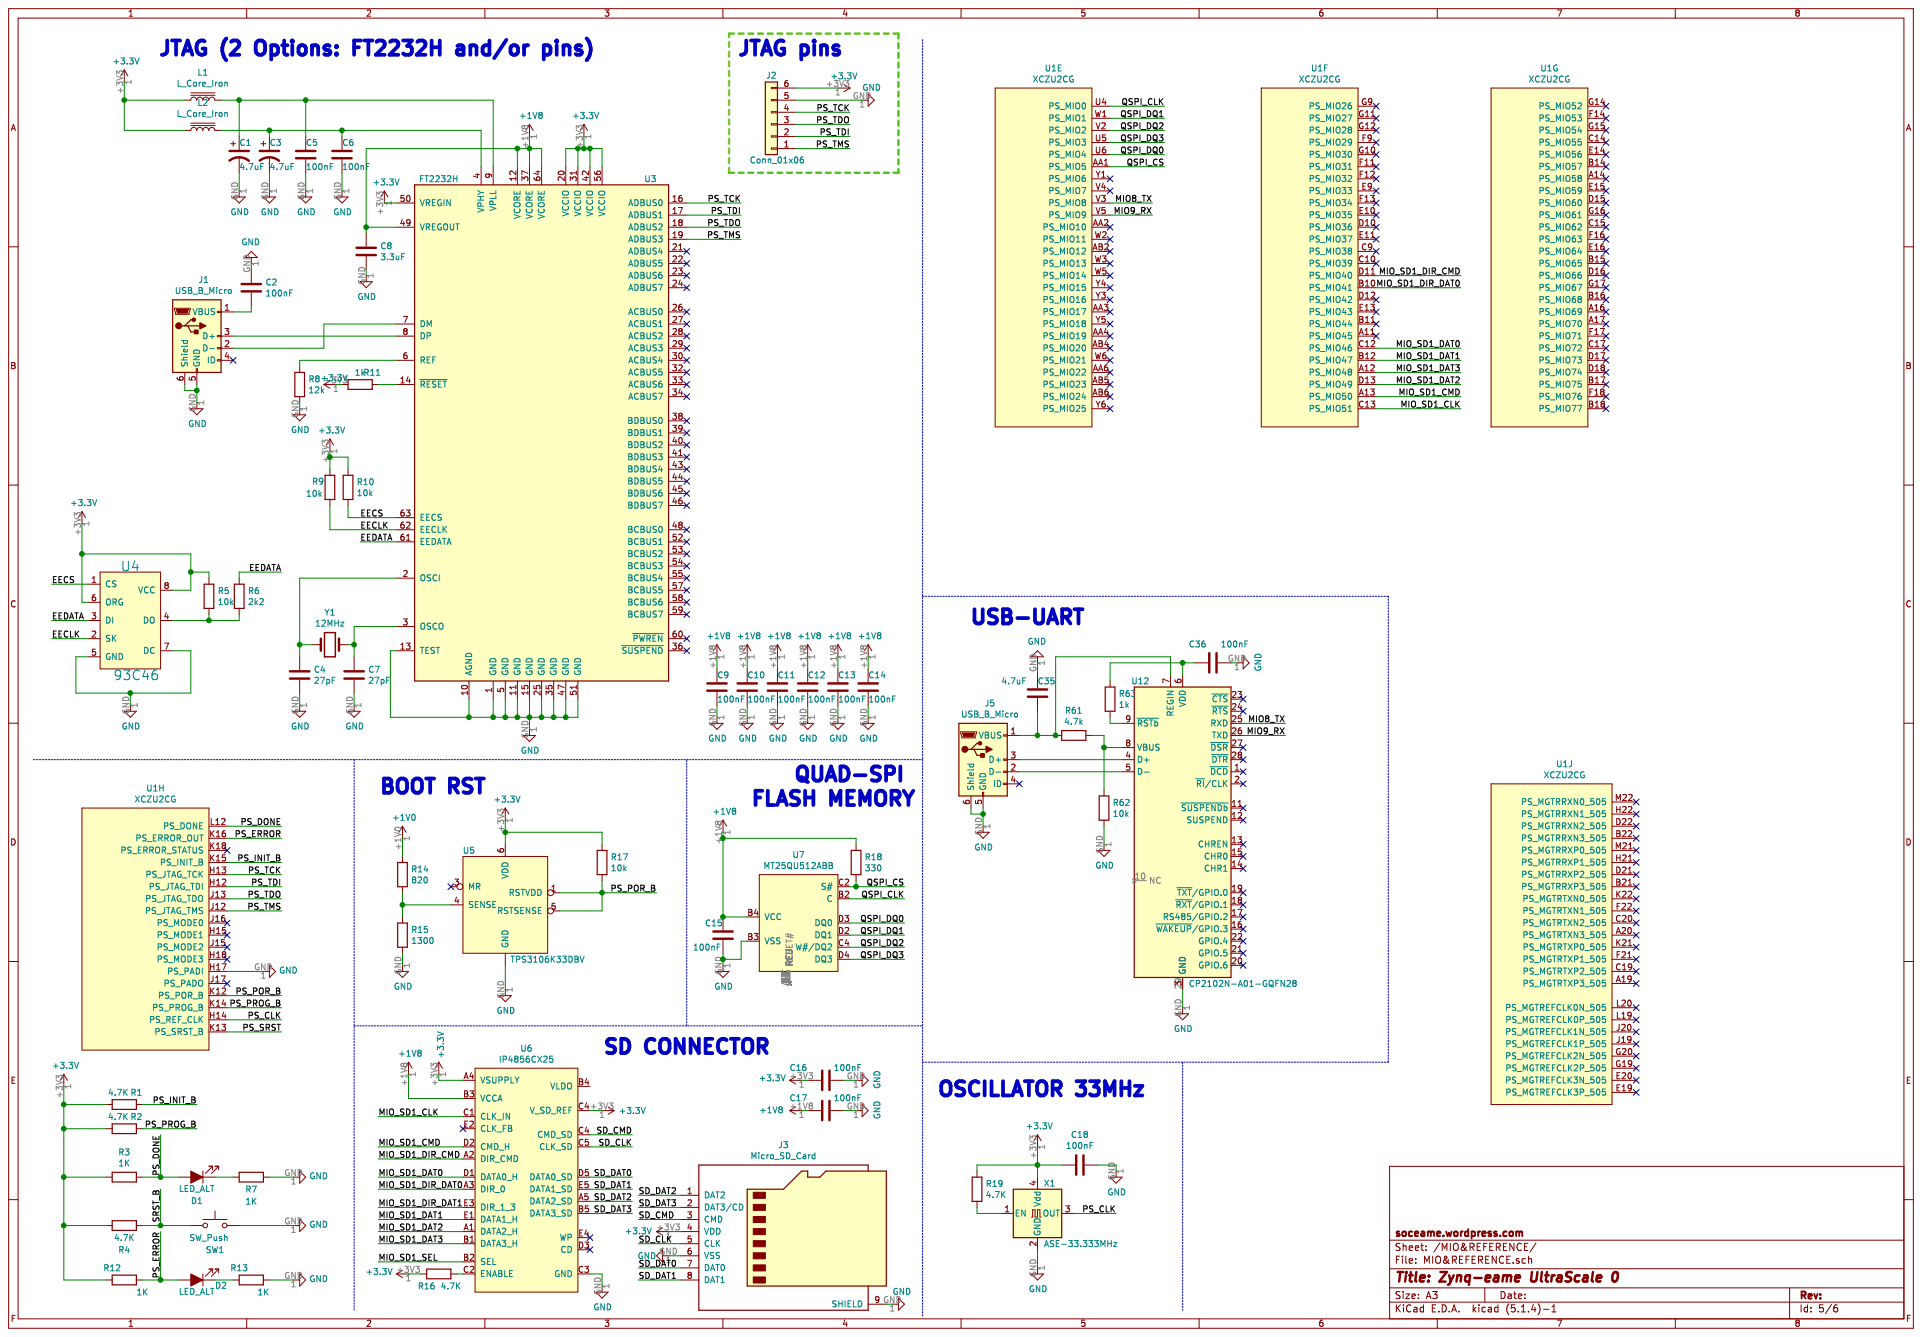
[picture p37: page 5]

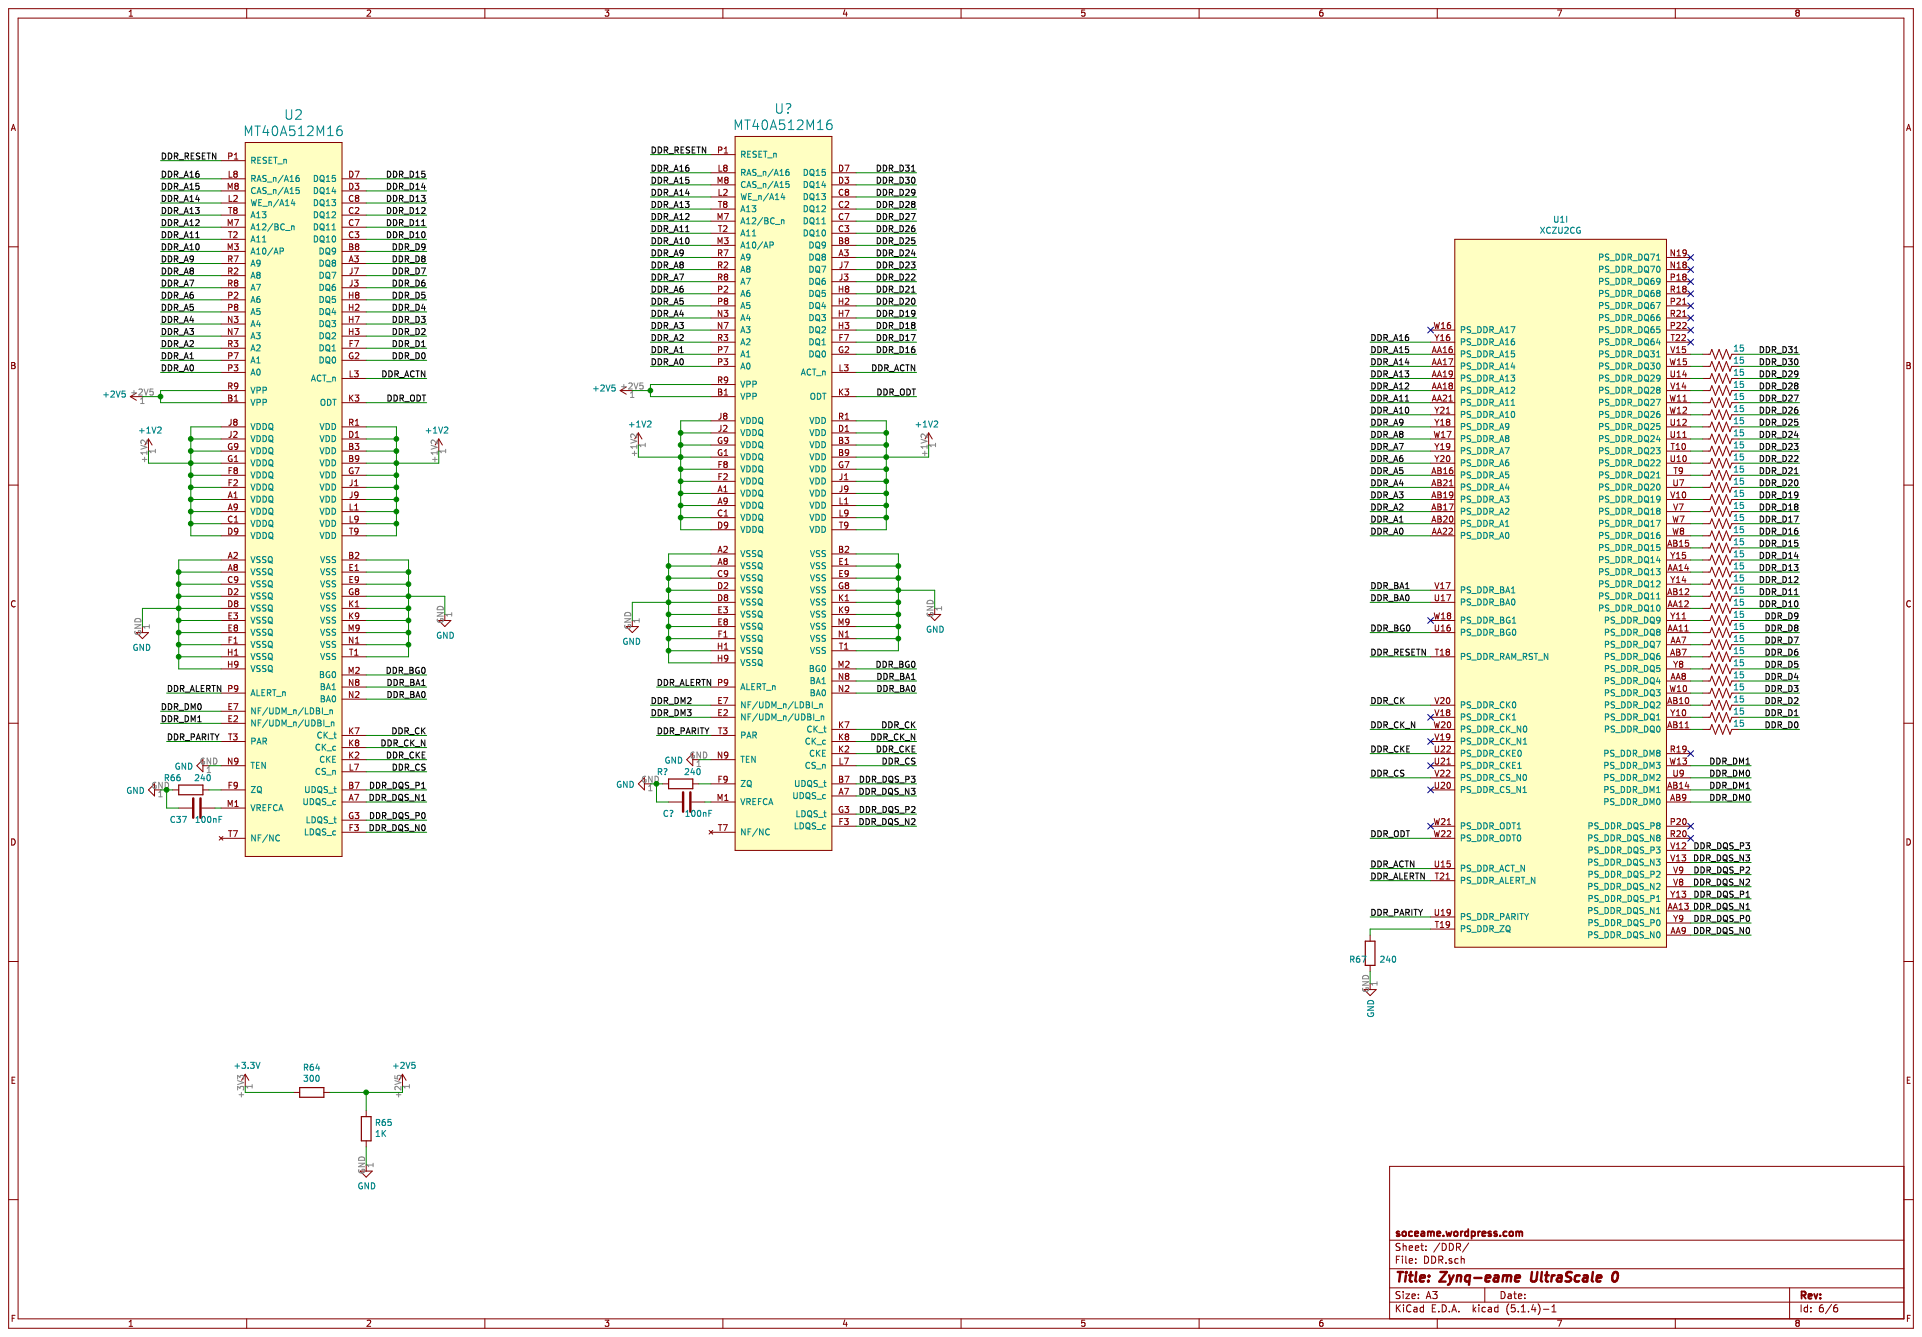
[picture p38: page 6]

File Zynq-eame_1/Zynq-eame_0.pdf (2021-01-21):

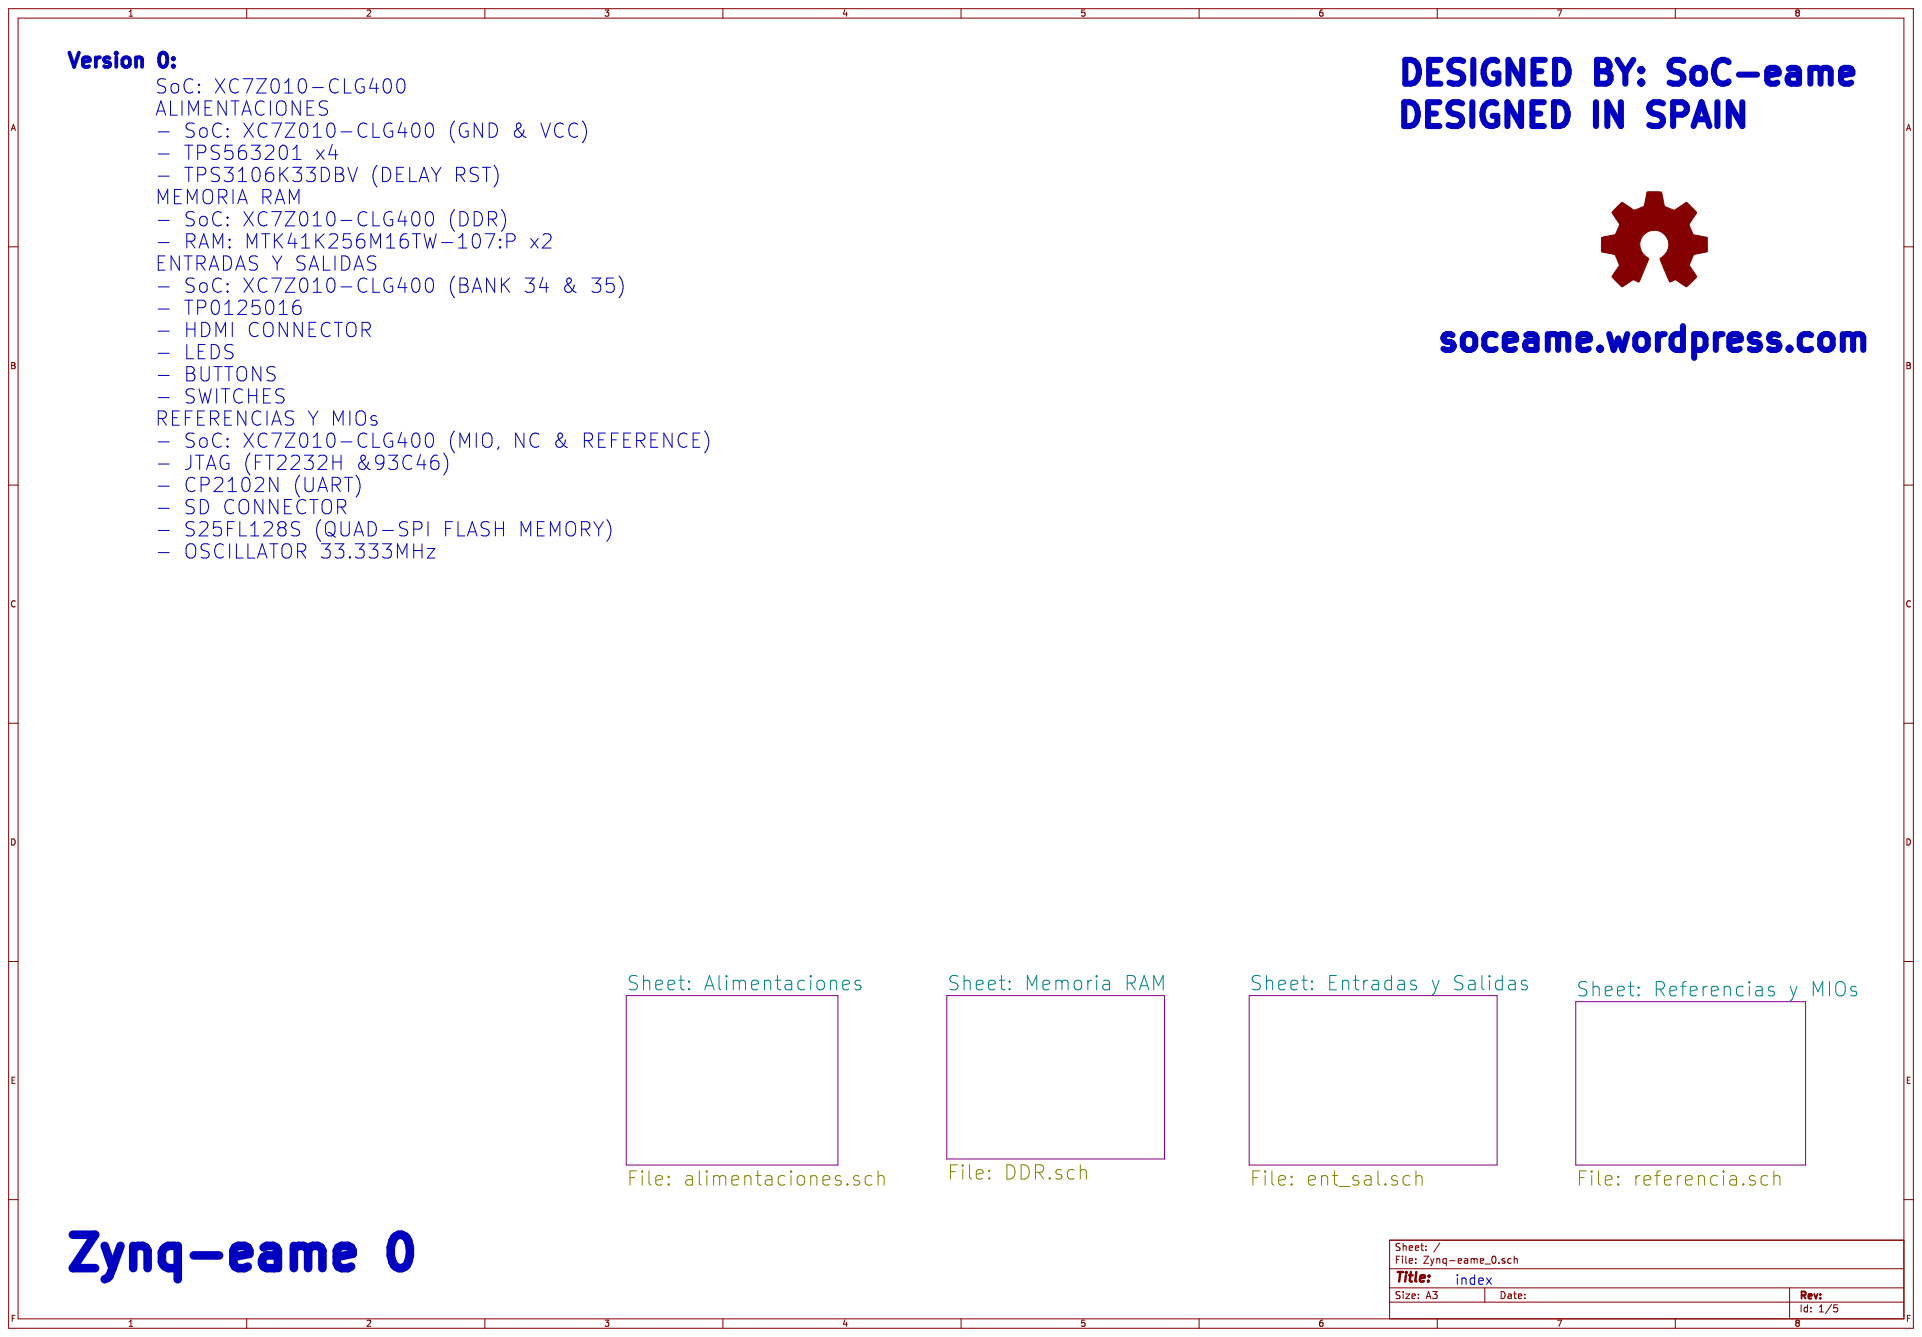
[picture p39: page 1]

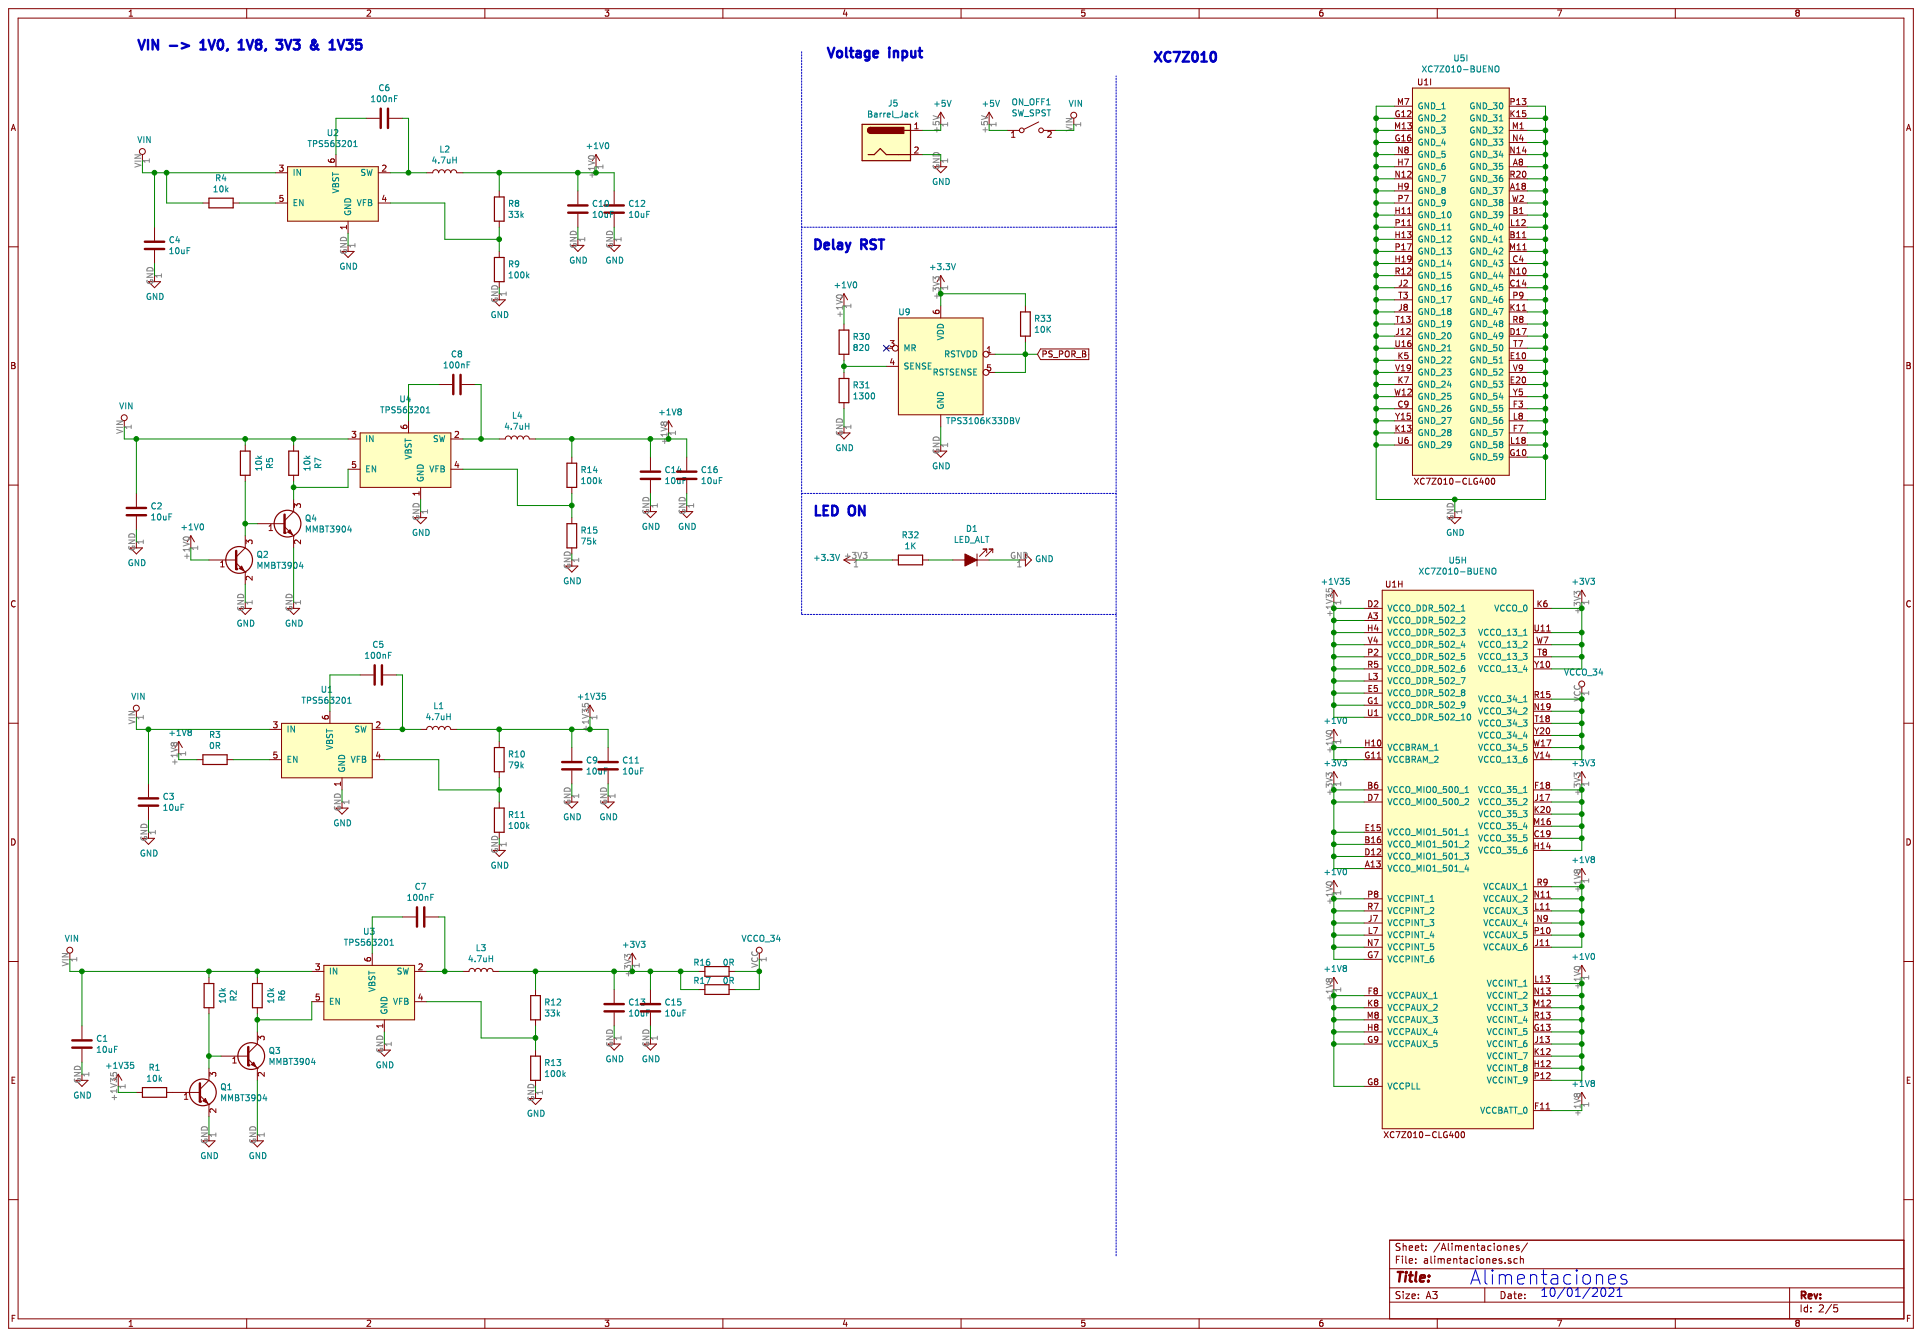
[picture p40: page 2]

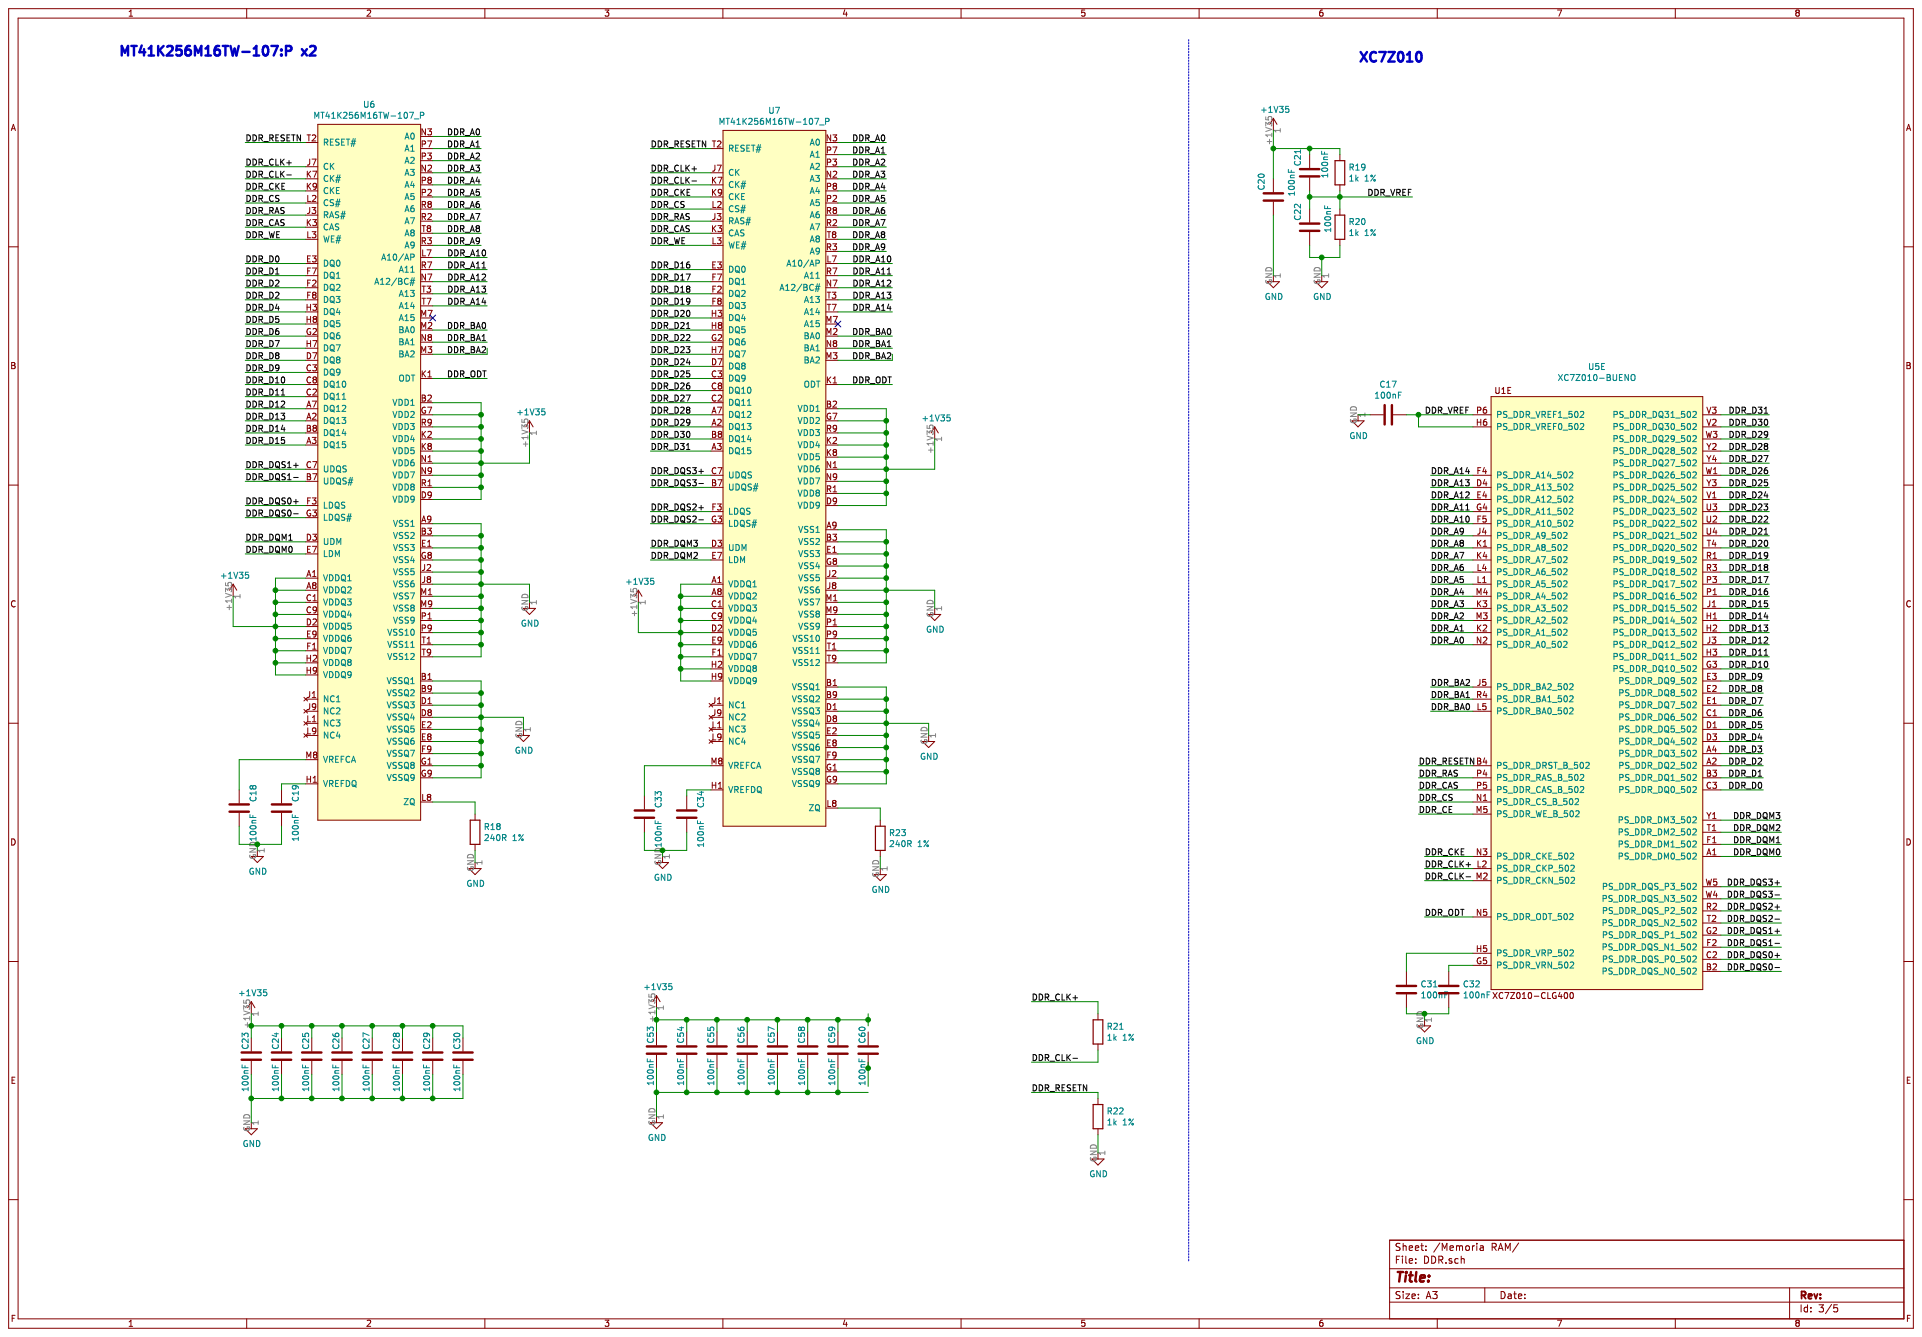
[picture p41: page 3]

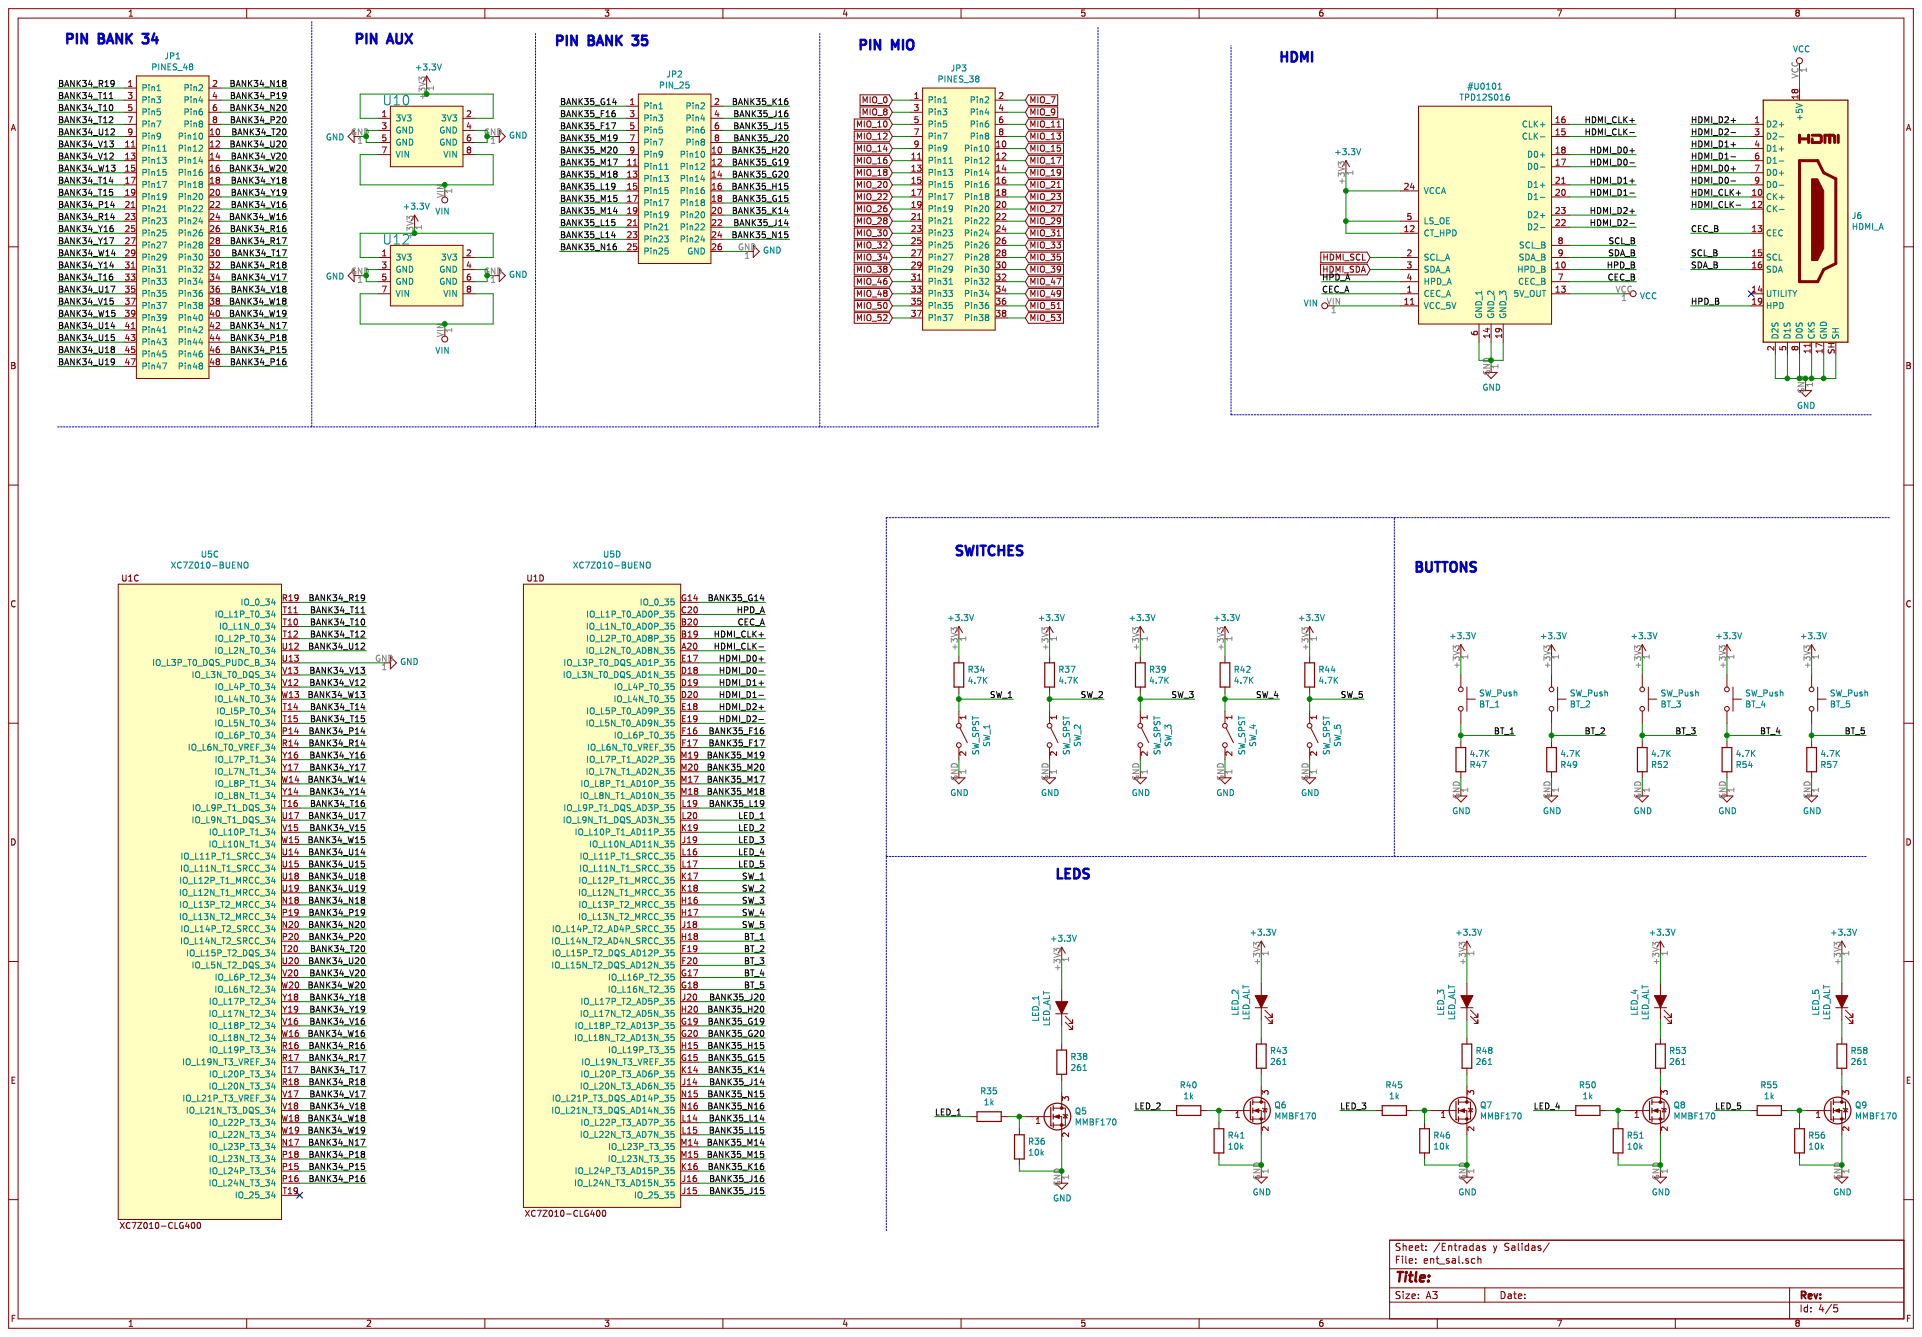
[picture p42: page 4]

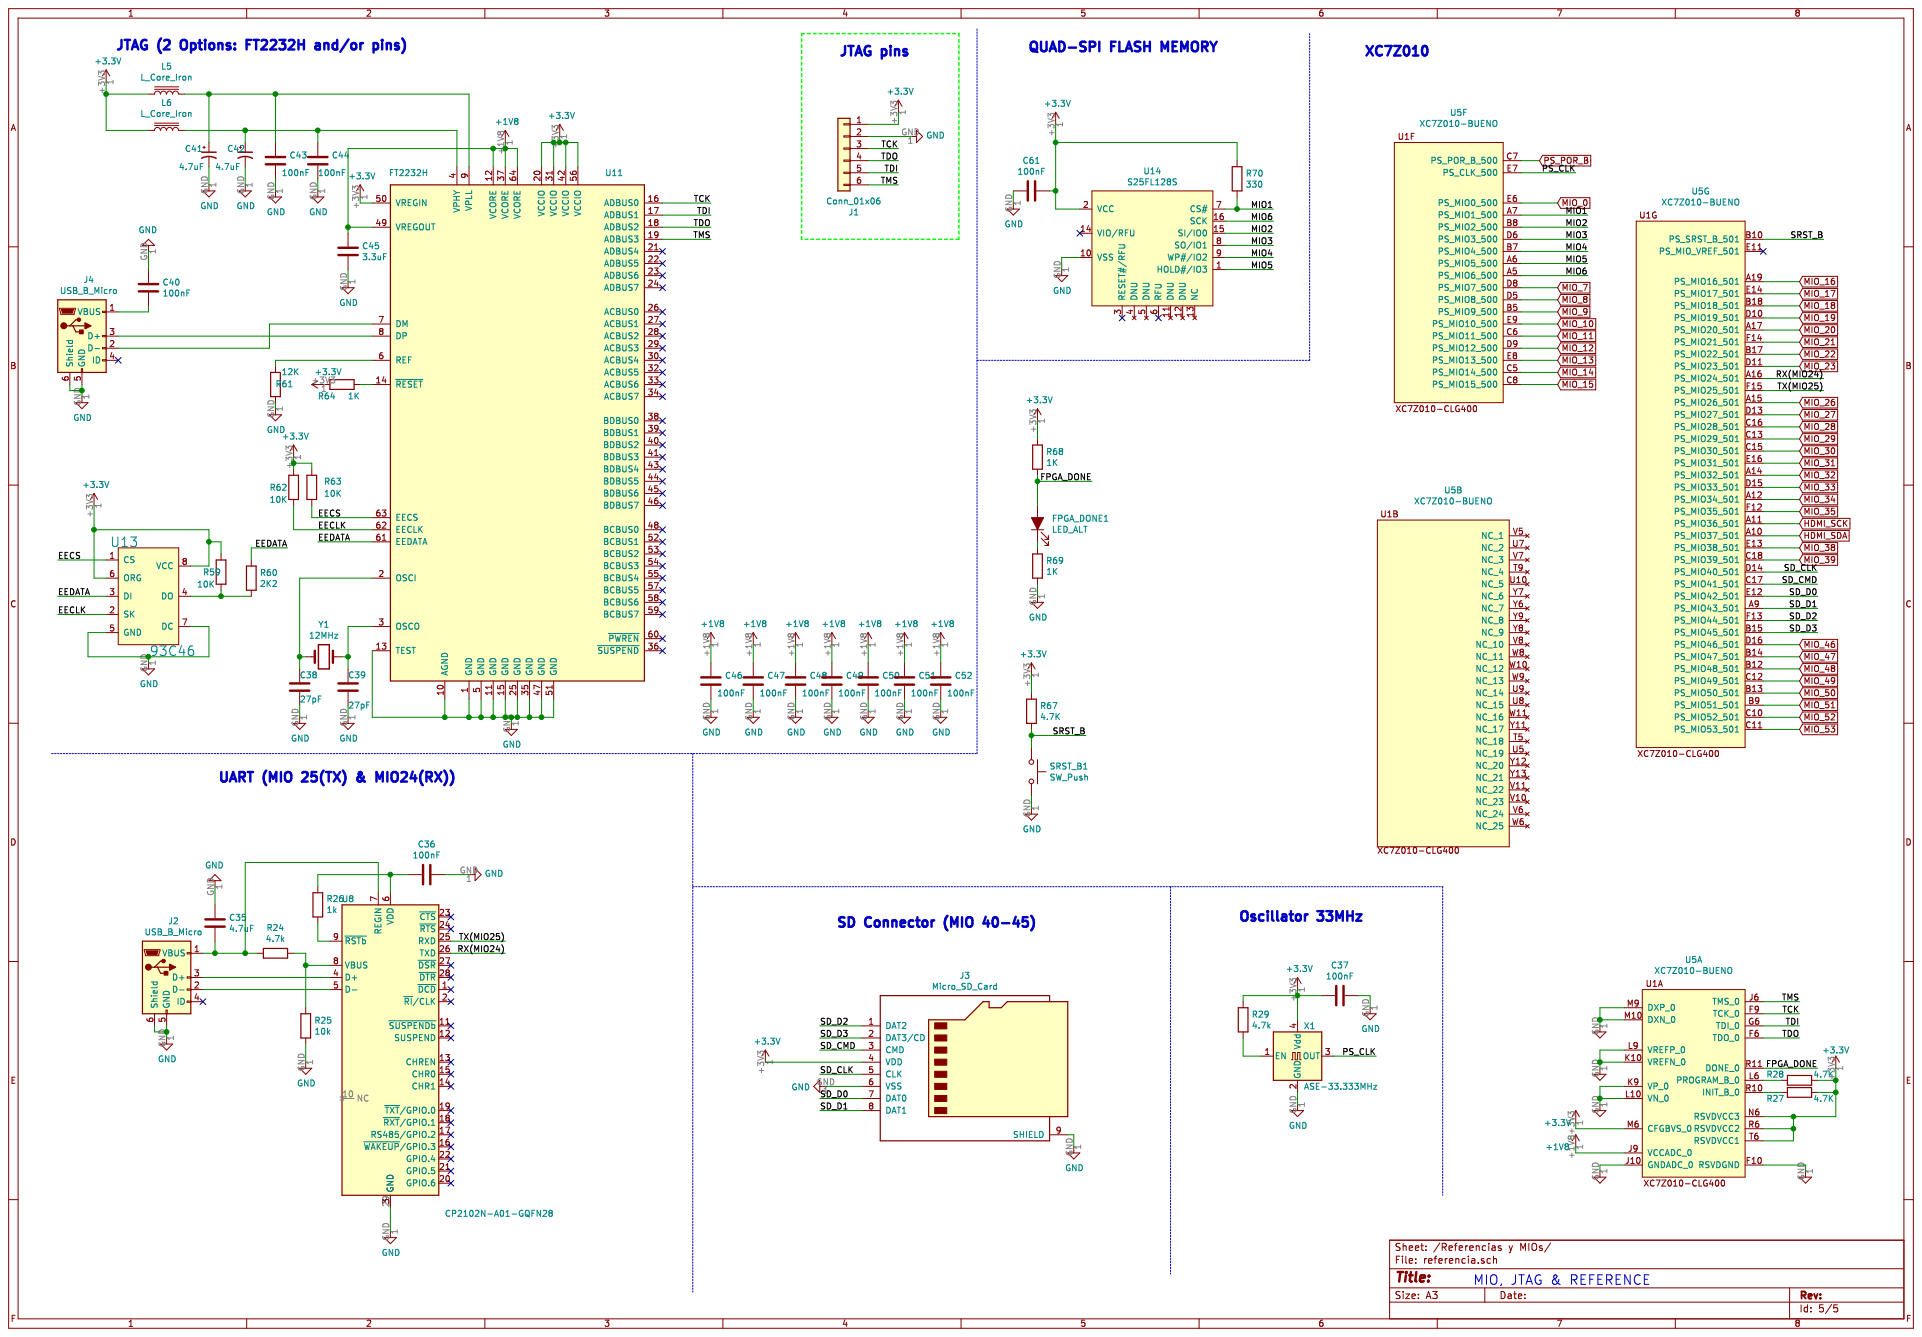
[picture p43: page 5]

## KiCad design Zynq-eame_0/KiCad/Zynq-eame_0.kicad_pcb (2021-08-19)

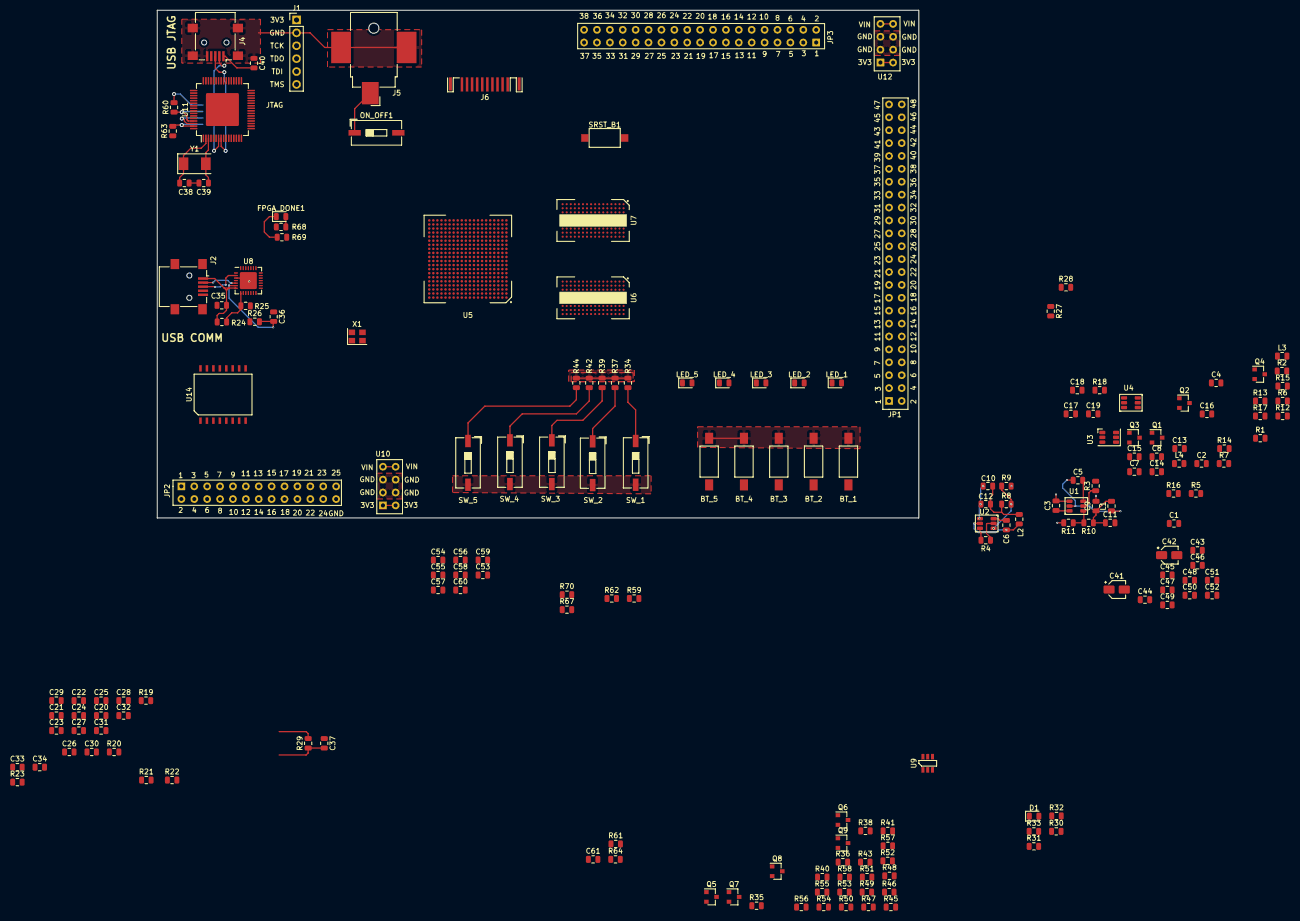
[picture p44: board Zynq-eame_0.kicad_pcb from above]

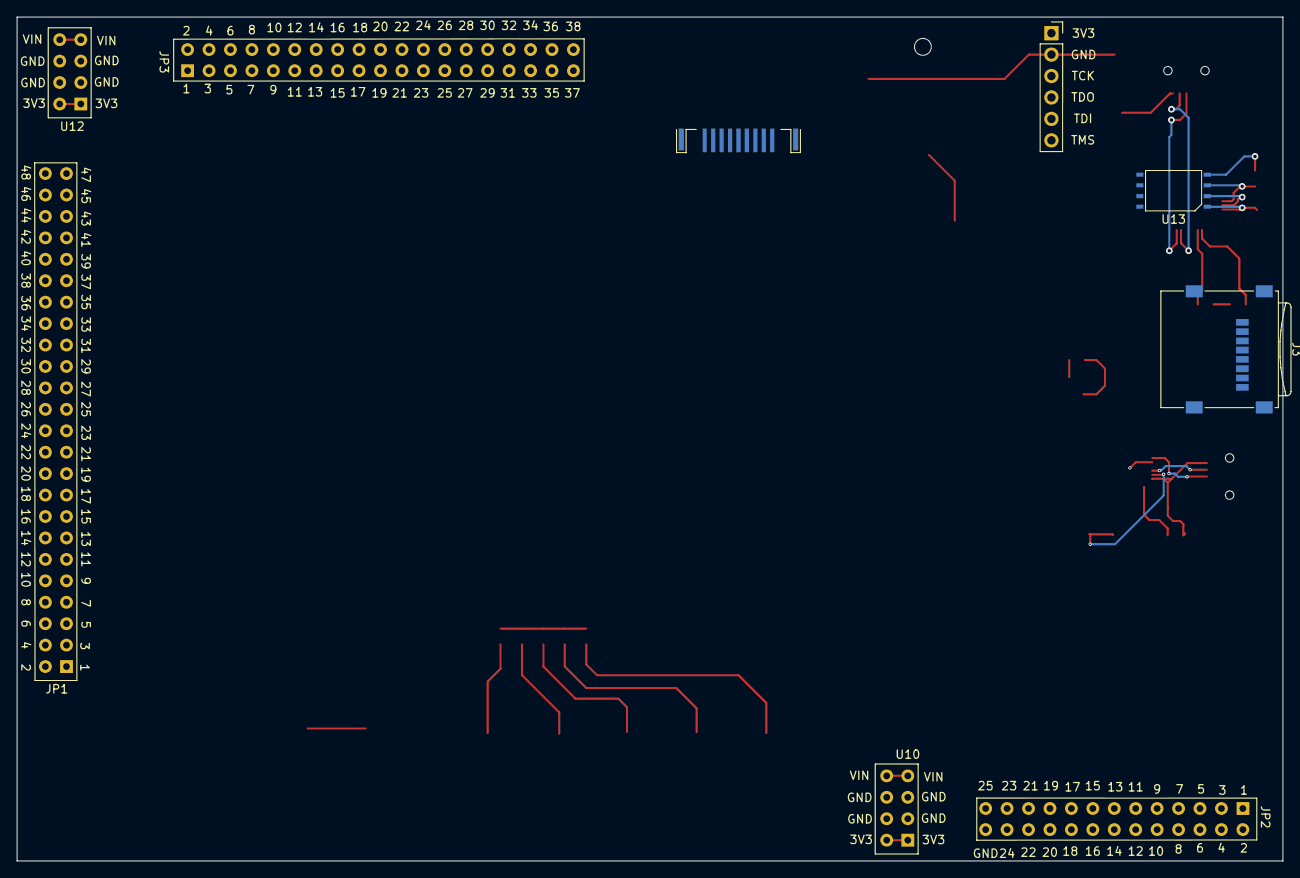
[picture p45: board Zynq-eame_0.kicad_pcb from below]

Board: 4 copper layers, 150.0 x 100.0 mm, 186 parts (2 on the bottom side), 302 nets.

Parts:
BT_1, BT_2, BT_3, BT_4, BT_5: SW_Push; SW_SPST_FSMSM
C1, C2, C3, C4, C9, C10, C11, C12, C13, C14, C15, C16: 10uF; C_0805_2012Metric
C5, C6, C7, C8, C17, C18, C19, C20, C21, C22, C23, C24, C25, C26, C27, C28, C29, C30, C31, C32, C33, C34, C37, C40, C43, C44, C53, C54, C55, C56, C57, C58, C59, C60, C61: 100nF; C_0805_2012Metric
C35: 4.7uF; R_0805_2012Metric
C36: 100nF; R_0805_2012Metric
C38, C39: 27pF; C_0805_2012Metric
C41, C42: 4.7uF; CP_Elec_3x5.4
C45: 3.3uF; C_0805_2012Metric
C46, C47, C48, C49, C50, C51, C52: C; C_0805_2012Metric
D1: LED_ALT; D_0805_2012Metric
FPGA_DONE1: LED_ALT; LED_0805_2012Metric
J1: Conn_01x06; PinHeader_1x06_P2.54mm_Vertical
J2, J4: USB_B_Micro; USB_Mini-B_Lumberg_2486_01_Horizontal
J3: Micro_SD_Card; microSD_HC_Wuerth_693072010801
J5: Barrel_Jack; BarrelJack_CUI_PJ-036AH-SMT_Horizontal
J6: HDMI_A; HDMI_A_Contact_Technology_HDMI-19APL2_Horizontal
JP1: PINES_48
JP2: PIN_25; PINES_40
JP3: PINES_38
L1, L2, L3, L4: 4.7uH; L_0805_2012Metric
LED_1, LED_2, LED_3, LED_4, LED_5: LED_ALT; LED_0805_2012Metric
ON_OFF1: SW_SPST; SW_DIP_SPSTx01_Slide_9.78x4.72mm_W8.61mm_P2.54mm
Q1, Q2, Q3, Q4: MMBT3904; SOT-23
Q5, Q6, Q7, Q8, Q9: MMBF170; SOT-23
R1, R2, R4, R5, R6, R7, R25, R36, R41, R46, R51, R56: 10k; R_0805_2012Metric
R3, R16, R17: 0R; R_0805_2012Metric
R8, R12: 33k; R_0805_2012Metric
R9, R11, R13, R14: 100k; R_0805_2012Metric
R10: 79k; R_0805_2012Metric
R15: 75k; R_0805_2012Metric
R18, R23: 240R 1%; R_0805_2012Metric
R19, R20, R21, R22: 1k 1%; R_0805_2012Metric
R24, R29: 4.7k; R_0805_2012Metric
R26, R35, R40, R45, R50, R55: 1k; R_0805_2012Metric
R27, R28, R34, R37, R39, R42, R44, R47, R49, R52, R54, R57, R67: 4.7K; R_0805_2012Metric
R30: 820; R_0805_2012Metric
R31: 1300; R_0805_2012Metric
R32, R64, R68, R69: 1K; R_0805_2012Metric
R33, R59, R62, R63: 10K; R_0805_2012Metric
R38, R43, R48, R53, R58: 261; R_0805_2012Metric
R60: 2K2; R_0805_2012Metric
R61: 12K; R_0805_2012Metric
R70: 330; R_0805_2012Metric
SRST_B1: SW_Push; SW_SPST_CK_RS282G05A3
SW_1, SW_2, SW_3, SW_4, SW_5: SW_SPST; SW_DIP_SPSTx01_Slide_9.78x4.72mm_W8.61mm_P2.54mm
U1, U2, U3, U4: TPS563201
U5: XC7Z010-BUENO; BGA-400_20x20_17.0x17.0mm
U6, U7: MT41K256M16TW-107_P; BGA-144_9x16_8.0x14.0mm
U8: CP2102N-A01-GQFN28; QFN-28-1EP_5x5mm_P0.5mm_EP3.35x3.35mm
U9: TPS3106K33DBV; SOT-23
U10, U12: PINES_ALIMENTACION; PINES_40
U11: FT2232H; LQFP-64-1EP_10x10mm_P0.5mm_EP6.5x6.5mm
U13: 93C46; EIAJ_SOIC
U14: S25FL128S; S03016-(SOIC-16)
X1: ASE-33.333MHz; Oscillator_SMD_Abracon_ASE-4Pin_3.2x2.5mm
Y1: 12MHz; Crystal_SMD_0603-2Pin_6.0x3.5mm

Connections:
+1V0: C10.1, C12.1, L2.2, Q2.1, R8.1, R30.1, U5.G7, U5.G11, U5.G13, U5.H10, U5.H12, U5.J7, U5.J13, U5.K12, U5.L7, U5.L13, U5.M12, U5.N7, U5.N13, U5.P8, U5.P12, U5.R7, U5.R13
+1V8: C14.1, C16.1, C45.1, C46.1, C47.1, C48.1, C49.1, C50.1, C51.1, C52.1, L4.2, R3.2, R14.1, U5.F8, U5.F11, U5.G8, U5.G9, U5.H8, U5.J9, U5.J11, U5.K8, U5.L11, U5.M8, U5.N9, U5.N11, U5.P10, U5.R9, U11.12, U11.37, U11.49, U11.64
+1V35: C9.1, C11.1, C20.1, C21.1, C23.1, C24.1, C25.1, C26.1, C27.1, C28.1, C29.1, C30.1, C53.1, C54.1, C55.1, C56.1, C57.1, C58.1, C59.1, L1.2, R1.2, R10.1, R19.1, U5.A3, U5.D2, U5.E5, U5.G1, U5.H4, U5.L3, U5.P2, U5.R5, U5.U1, U5.V4, U6.A1, U6.A8, U6.B2, U6.C1, U6.C9, U6.D2, U6.D9, U6.E9, U6.F1, U6.G7, U6.H2, U6.H9, U6.K2, U6.K8, U6.N1, U6.N9, U6.R1, U6.R9, U7.A1, U7.A8, U7.B2, U7.C1, U7.C9, U7.D2, U7.D9, U7.E9, U7.F1, U7.G7, U7.H2, U7.H9, U7.K2, U7.K8, U7.N1, U7.N9, U7.R1, U7.R9
+3V3: BT_1.2, BT_2.2, BT_3.2, BT_4.2, BT_5.2, C13.1, C15.1, C37.2, C61.1, J1.1, J3.4, L3.2, LED_1.2, LED_2.2, LED_3.2, LED_4.2, LED_5.2, R12.1, R16.1, R17.1, R27.1, R28.1, R29.1, R32.2, R33.1, R34.1, R37.1, R39.1, R42.1, R44.1, R59.1, R62.1, R63.1, R64.1, R67.1, R68.1, R70.1, U5.A13, U5.B6, U5.B16, U5.C19, U5.D7, U5.D12, U5.E15, U5.F18, U5.H14, U5.J17, U5.K6, U5.K20, U5.M6, U5.M16, U5.N6, U5.R6, U5.T6, U5.T8, U5.U11, U5.W7, U5.Y10, U9.6, U10.1, U10.2, U11.20, U11.31, U11.42, U11.50, U11.56, U12.1, U12.2, U13.6, U13.8, U14.2, X1.4
+5V: J5.1, ON_OFF1.1
/Entradas y Salidas/BANK34_N17: JP1.42, U5.N17
/Entradas y Salidas/BANK34_N18: JP1.2, U5.N18
/Entradas y Salidas/BANK34_N20: JP1.6, U5.N20
/Entradas y Salidas/BANK34_P14: JP1.21, U5.P14
/Entradas y Salidas/BANK34_P15: JP1.46, U5.P15
/Entradas y Salidas/BANK34_P16: JP1.48, U5.P16
/Entradas y Salidas/BANK34_P18: JP1.44, U5.P18
/Entradas y Salidas/BANK34_P19: JP1.4, U5.P19
/Entradas y Salidas/BANK34_P20: JP1.8, U5.P20
/Entradas y Salidas/BANK34_R14: JP1.23, U5.R14
/Entradas y Salidas/BANK34_R16: JP1.26, U5.R16
/Entradas y Salidas/BANK34_R17: JP1.28, U5.R17
/Entradas y Salidas/BANK34_R18: JP1.32, U5.R18
/Entradas y Salidas/BANK34_R19: JP1.1, U5.R19
/Entradas y Salidas/BANK34_T10: JP1.5, U5.T10
/Entradas y Salidas/BANK34_T11: JP1.3, U5.T11
/Entradas y Salidas/BANK34_T12: JP1.7, U5.T12
/Entradas y Salidas/BANK34_T14: JP1.17, U5.T14
/Entradas y Salidas/BANK34_T15: JP1.19, U5.T15
/Entradas y Salidas/BANK34_T16: JP1.33, U5.T16
/Entradas y Salidas/BANK34_T17: JP1.30, U5.T17
/Entradas y Salidas/BANK34_T20: JP1.10, U5.T20
/Entradas y Salidas/BANK34_U12: JP1.9, U5.U12
/Entradas y Salidas/BANK34_U14: JP1.41, U5.U14
/Entradas y Salidas/BANK34_U15: JP1.43, U5.U15
/Entradas y Salidas/BANK34_U17: JP1.35, U5.U17
/Entradas y Salidas/BANK34_U18: JP1.45, U5.U18
/Entradas y Salidas/BANK34_U19: JP1.47, U5.U19
/Entradas y Salidas/BANK34_U20: JP1.12, U5.U20
/Entradas y Salidas/BANK34_V12: JP1.13, U5.V12
/Entradas y Salidas/BANK34_V13: JP1.11, U5.V13
/Entradas y Salidas/BANK34_V15: JP1.37, U5.V15
/Entradas y Salidas/BANK34_V16: JP1.22, U5.V16
/Entradas y Salidas/BANK34_V17: JP1.34, U5.V17
/Entradas y Salidas/BANK34_V18: JP1.36, U5.V18
/Entradas y Salidas/BANK34_V20: JP1.14, U5.V20
/Entradas y Salidas/BANK34_W13: JP1.15, U5.W13
/Entradas y Salidas/BANK34_W14: JP1.29, U5.W14
/Entradas y Salidas/BANK34_W15: JP1.39, U5.W15
/Entradas y Salidas/BANK34_W16: JP1.24, U5.W16
/Entradas y Salidas/BANK34_W18: JP1.38, U5.W18
/Entradas y Salidas/BANK34_W19: JP1.40, U5.W19
/Entradas y Salidas/BANK34_W20: JP1.16, U5.W20
/Entradas y Salidas/BANK34_Y14: JP1.31, U5.Y14
/Entradas y Salidas/BANK34_Y16: JP1.25, U5.Y16
/Entradas y Salidas/BANK34_Y17: JP1.27, U5.Y17
/Entradas y Salidas/BANK34_Y18: JP1.18, U5.Y18
/Entradas y Salidas/BANK34_Y19: JP1.20, U5.Y19
/Entradas y Salidas/BANK35_F16: JP2.3, U5.F16
/Entradas y Salidas/BANK35_F17: JP2.5, U5.F17
/Entradas y Salidas/BANK35_G14: JP2.1, U5.G14
/Entradas y Salidas/BANK35_G15: JP2.18, U5.G15
/Entradas y Salidas/BANK35_G19: JP2.12, U5.G19
/Entradas y Salidas/BANK35_G20: JP2.14, U5.G20
/Entradas y Salidas/BANK35_H15: JP2.16, U5.H15
/Entradas y Salidas/BANK35_H20: JP2.10, U5.H20
/Entradas y Salidas/BANK35_J14: JP2.22, U5.J14
/Entradas y Salidas/BANK35_J15: JP2.6, U5.J15
/Entradas y Salidas/BANK35_J16: JP2.4, U5.J16
/Entradas y Salidas/BANK35_J20: JP2.8, U5.J20
/Entradas y Salidas/BANK35_K14: JP2.20, U5.K14
/Entradas y Salidas/BANK35_K16: JP2.2, U5.K16
/Entradas y Salidas/BANK35_L14: JP2.23, U5.L14
/Entradas y Salidas/BANK35_L15: JP2.21, U5.L15
/Entradas y Salidas/BANK35_L19: JP2.15, U5.L19
/Entradas y Salidas/BANK35_M14: JP2.19, U5.M14
/Entradas y Salidas/BANK35_M15: JP2.17, U5.M15
/Entradas y Salidas/BANK35_M17: JP2.11, U5.M17
/Entradas y Salidas/BANK35_M18: JP2.13, U5.M18
/Entradas y Salidas/BANK35_M19: JP2.7, U5.M19
/Entradas y Salidas/BANK35_M20: JP2.9, U5.M20
/Entradas y Salidas/BANK35_N15: JP2.24, U5.N15
/Entradas y Salidas/BANK35_N16: JP2.25, U5.N16
/Entradas y Salidas/BT_1: BT_1.1, R47.2, U5.H18
/Entradas y Salidas/BT_2: BT_2.1, R49.2, U5.F19
/Entradas y Salidas/BT_3: BT_3.1, R52.2, U5.F20
/Entradas y Salidas/BT_4: BT_4.1, R54.2, U5.G17
/Entradas y Salidas/BT_5: BT_5.1, R57.2, U5.G18
/Entradas y Salidas/HDMI_CLK+: J6.10, U5.B19
/Entradas y Salidas/HDMI_CLK-: J6.12, U5.A20
/Entradas y Salidas/HDMI_D0+: J6.7, U5.E17
/Entradas y Salidas/HDMI_D0-: J6.9, U5.D18
/Entradas y Salidas/HDMI_D1+: J6.4, U5.D19
/Entradas y Salidas/HDMI_D1-: J6.6, U5.D20
/Entradas y Salidas/HDMI_D2+: J6.1, U5.E18
/Entradas y Salidas/HDMI_D2-: J6.3, U5.E19
/Entradas y Salidas/LED_1: R35.1, U5.L20
/Entradas y Salidas/LED_2: R40.1, U5.K19
/Entradas y Salidas/LED_3: R45.1, U5.J19
/Entradas y Salidas/LED_4: R50.1, U5.L16
/Entradas y Salidas/LED_5: R55.1, U5.L17
/Entradas y Salidas/SW_1: R34.2, SW_1.1, U5.K17
/Entradas y Salidas/SW_2: R37.2, SW_2.1, U5.K18
/Entradas y Salidas/SW_3: R39.2, SW_3.1, U5.H16
/Entradas y Salidas/SW_4: R42.2, SW_4.1, U5.H17
/Entradas y Salidas/SW_5: R44.2, SW_5.1, U5.J18
/Memoria RAM/DDR_A0: U5.N2, U6.N3, U7.N3
/Memoria RAM/DDR_A1: U5.K2, U6.P7, U7.P7
/Memoria RAM/DDR_A2: U5.M3, U6.P3, U7.P3
/Memoria RAM/DDR_A3: U5.K3, U6.N2, U7.N2
/Memoria RAM/DDR_A4: U5.M4, U6.P8, U7.P8
/Memoria RAM/DDR_A5: U5.L1, U6.P2, U7.P2
/Memoria RAM/DDR_A6: U5.L4, U6.R8, U7.R8
/Memoria RAM/DDR_A7: U5.K4, U6.R2, U7.R2
/Memoria RAM/DDR_A8: U5.K1, U6.T8, U7.T8
/Memoria RAM/DDR_A9: U5.J4, U6.R3, U7.R3
/Memoria RAM/DDR_A10: U5.F5, U6.L7, U7.L7
/Memoria RAM/DDR_A11: U5.G4, U6.R7, U7.R7
/Memoria RAM/DDR_A12: U5.E4, U6.N7, U7.N7
/Memoria RAM/DDR_A13: U5.D4, U6.T3, U7.T3
/Memoria RAM/DDR_A14: U5.F4, U6.T7, U7.T7
/Memoria RAM/DDR_BA0: U5.L5, U6.M2, U7.M2
/Memoria RAM/DDR_BA1: U5.R4, U6.N8, U7.N8
/Memoria RAM/DDR_BA2: U5.J5, U6.M3, U7.M3
/Memoria RAM/DDR_CAS: U5.P5, U6.K3, U7.K3
/Memoria RAM/DDR_CKE: U5.N3, U6.K9, U7.K9
/Memoria RAM/DDR_CLK+: R21.1, U5.L2, U6.J7, U7.J7
/Memoria RAM/DDR_CLK-: R21.2, U5.M2, U6.K7, U7.K7
/Memoria RAM/DDR_CS: U5.N1, U6.L2, U7.L2
/Memoria RAM/DDR_D0: U5.C3, U6.E3
/Memoria RAM/DDR_D1: U5.B3, U6.F7
/Memoria RAM/DDR_D2: U5.A2, U6.F2, U6.F8
/Memoria RAM/DDR_D4: U5.D3, U6.H3
/Memoria RAM/DDR_D5: U5.D1, U6.H8
/Memoria RAM/DDR_D6: U5.C1, U6.G2
/Memoria RAM/DDR_D7: U5.E1, U6.H7
/Memoria RAM/DDR_D8: U5.E2, U6.D7
/Memoria RAM/DDR_D9: U5.E3, U6.C3
/Memoria RAM/DDR_D10: U5.G3, U6.C8
/Memoria RAM/DDR_D11: U5.H3, U6.C2
/Memoria RAM/DDR_D12: U5.J3, U6.A7
/Memoria RAM/DDR_D13: U5.H2, U6.A2
/Memoria RAM/DDR_D14: U5.H1, U6.B8
/Memoria RAM/DDR_D15: U5.J1, U6.A3
/Memoria RAM/DDR_D16: U5.P1, U7.E3
/Memoria RAM/DDR_D17: U5.P3, U7.F7
/Memoria RAM/DDR_D18: U5.R3, U7.F2
/Memoria RAM/DDR_D19: U5.R1, U7.F8
/Memoria RAM/DDR_D20: U5.T4, U7.H3
/Memoria RAM/DDR_D21: U5.U4, U7.H8
/Memoria RAM/DDR_D22: U5.U2, U7.G2
/Memoria RAM/DDR_D23: U5.U3, U7.H7
/Memoria RAM/DDR_D24: U5.V1, U7.D7
/Memoria RAM/DDR_D25: U5.Y3, U7.C3
/Memoria RAM/DDR_D26: U5.W1, U7.C8
/Memoria RAM/DDR_D27: U5.Y4, U7.C2
/Memoria RAM/DDR_D28: U5.Y2, U7.A7
/Memoria RAM/DDR_D29: U5.W3, U7.A2
/Memoria RAM/DDR_D30: U5.V2, U7.B8
/Memoria RAM/DDR_D31: U5.V3, U7.A3
/Memoria RAM/DDR_DQM0: U5.A1, U6.E7
/Memoria RAM/DDR_DQM1: U5.F1, U6.D3
/Memoria RAM/DDR_DQM2: U5.T1, U7.E7
/Memoria RAM/DDR_DQM3: U5.Y1, U7.D3
/Memoria RAM/DDR_DQS0+: U5.C2, U6.F3
/Memoria RAM/DDR_DQS0-: U5.B2, U6.G3
/Memoria RAM/DDR_DQS1+: U5.G2, U6.C7
/Memoria RAM/DDR_DQS1-: U5.F2, U6.B7
/Memoria RAM/DDR_DQS2+: U5.R2, U7.F3
/Memoria RAM/DDR_DQS2-: U5.T2, U7.G3
/Memoria RAM/DDR_DQS3+: U5.W5, U7.C7
/Memoria RAM/DDR_DQS3-: U5.W4, U7.B7
/Memoria RAM/DDR_ODT: U5.N5, U6.K1, U7.K1
/Memoria RAM/DDR_RAS: U5.P4, U6.J3, U7.J3
/Memoria RAM/DDR_RESETN: R22.1, U5.B4, U6.T2, U7.T2
/Memoria RAM/DDR_VREF: C17.1, C21.2, C22.1, R19.2, R20.1, U5.H6, U5.P6
/Memoria RAM/DDR_WE: U6.L3, U7.L3
/Referencias y MIOs/EECLK: R62.2, U11.62, U13.2
/Referencias y MIOs/EECS: R63.2, U11.63, U13.1
/Referencias y MIOs/EEDATA: R60.1, U11.61, U13.3
/Referencias y MIOs/FPGA_DONE: FPGA_DONE1.2, R68.2, U5.R11
/Referencias y MIOs/MIO1: R70.2, U5.A7, U14.7
/Referencias y MIOs/MIO2: U5.B8, U14.15
/Referencias y MIOs/MIO3: U5.D6, U14.8
/Referencias y MIOs/MIO4: U5.B7, U14.9
/Referencias y MIOs/MIO5: U5.A6, U14.1
/Referencias y MIOs/MIO6: U5.A5, U14.16
/Referencias y MIOs/PS_CLK: U5.E7, X1.3
/Referencias y MIOs/RX(MIO24): U5.A16, U8.26
/Referencias y MIOs/SD_CLK: J3.5, U5.D14
/Referencias y MIOs/SD_CMD: J3.3, U5.C17
/Referencias y MIOs/SD_D0: J3.7, U5.E12
/Referencias y MIOs/SD_D1: J3.8, U5.A9
/Referencias y MIOs/SD_D2: J3.1, U5.F13
/Referencias y MIOs/SD_D3: J3.2, U5.B15
/Referencias y MIOs/SRST_B: R67.2, SRST_B1.1, U5.B10
/Referencias y MIOs/TCK: J1.3, U5.F9, U11.16
/Referencias y MIOs/TDI: J1.5, U5.G6, U11.17
/Referencias y MIOs/TDO: J1.4, U5.F6, U11.18
/Referencias y MIOs/TMS: J1.6, U5.J6, U11.19
/Referencias y MIOs/TX(MIO25): U5.F15, U8.25
GND: C1.2, C2.2, C3.2, C4.2, C9.2, C10.2, C11.2, C12.2, C13.2, C14.2, C15.2, C16.2, C17.2, C18.2, C19.2, C20.2, C22.2, C23.2, C24.2, C25.2, C26.2, C27.2, C28.2, C29.2, C30.2, C31.2, C32.2, C33.2, C34.2, C35.1, C36.1, C37.1, C38.2, C39.2, C40.1, C41.2, C42.2, C43.2, C44.2, C45.2, C46.2, C47.2, C48.2, C49.2, C50.2, C51.2, C52.2, C53.2, C54.2, C55.2, C56.2, C57.2, C58.2, C59.2, C61.2, D1.1, J1.2, J2.5, J2.6, J3.6, J3.9, J4.5, J4.6, J5.2, J6.2, J6.5, J6.8, J6.11, J6.17, J6.SH, JP2.26, Q1.2, Q2.2, Q3.2, Q4.2, Q5.2, Q6.2, Q7.2, Q8.2, Q9.2, R9.2, R11.2, R13.2, R15.2, R18.2, R20.2, R22.2, R23.2, R25.2, R31.2, R36.2, R41.2, R46.2, R47.1, R49.1, R51.2, R52.1, R54.1, R56.2, R57.1, R61.1, R69.2, SRST_B1.2, SW_1.2, SW_2.2, SW_3.2, SW_4.2, SW_5.2, U1.1, U2.1, U3.1, U4.1, U5.A8, U5.A18, U5.B1, U5.B11, U5.C4, U5.C9, U5.C14, U5.D17, U5.E10, U5.E20, U5.F3, U5.F7, U5.F10, U5.G10, U5.G12, U5.G16, U5.H7, U5.H9, U5.H11, U5.H13, U5.H19, U5.J2, U5.J8, U5.J10, U5.J12, U5.K5, U5.K7, U5.K9, U5.K10, U5.K11, U5.K13, U5.K15, U5.L8, U5.L9, U5.L10, U5.L12, U5.L18, U5.M1, U5.M7, U5.M9, U5.M10, U5.M11, U5.M13, U5.N4, U5.N8, U5.N10, U5.N12, U5.N14, U5.P7, U5.P9, U5.P11, U5.P13, U5.P17, U5.R8, U5.R12, U5.R20, U5.T3, U5.T7, U5.T13, U5.U6, U5.U13, U5.U16, U5.V9, U5.V19, U5.W2, U5.W12, U5.Y5, U5.Y15, U6.A9, U6.B1, U6.B3, U6.B9, U6.D1, U6.D8, U6.E1, U6.E2, U6.E8, U6.F9, U6.G1, U6.G8, U6.G9, U6.J2, U6.J8, U6.M1, U6.M9, U6.P1, U6.P9, U6.T1, U6.T9, U7.A9, U7.B1, U7.B3, U7.B9, U7.D1, U7.D8, U7.E1, U7.E2, U7.E8, U7.F9, U7.G1, U7.G8, U7.G9, U7.J2, U7.J8, U7.M1, U7.M9, U7.P1, U7.P9, U7.T1, U7.T9, U8.3, U8.29, U10.3, U10.4, U10.5, U10.6, U11.1, U11.5, U11.10, U11.11, U11.13, U11.15, U11.25, U11.35, U11.47, U11.51, U12.3, U12.4, U12.5, U12.6, U13.5, U13.7, U14.10, X1.2
MIO_0: JP3.1, U5.E6
MIO_7: JP3.2, U5.D8
MIO_8: JP3.3, U5.D5
MIO_9: JP3.4, U5.B5
MIO_10: JP3.5, U5.E9
MIO_11: JP3.6, U5.C6
MIO_12: JP3.7, U5.D9
MIO_13: JP3.8, U5.E8
MIO_14: JP3.9, U5.C5
MIO_15: JP3.10, U5.C8
MIO_16: JP3.11, U5.A19
MIO_17: JP3.12, U5.E14
MIO_18: JP3.13, U5.B18
MIO_19: JP3.14, U5.D10
MIO_20: JP3.15, U5.A17
MIO_21: JP3.16, U5.F14
MIO_22: JP3.17, U5.B17
MIO_23: JP3.18, U5.D11
MIO_26: JP3.19, U5.A15
MIO_27: JP3.20, U5.D13
MIO_28: JP3.21, U5.C16
MIO_29: JP3.22, U5.C13
MIO_30: JP3.23, U5.C15
MIO_31: JP3.24, U5.E16
MIO_32: JP3.25, U5.A14
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

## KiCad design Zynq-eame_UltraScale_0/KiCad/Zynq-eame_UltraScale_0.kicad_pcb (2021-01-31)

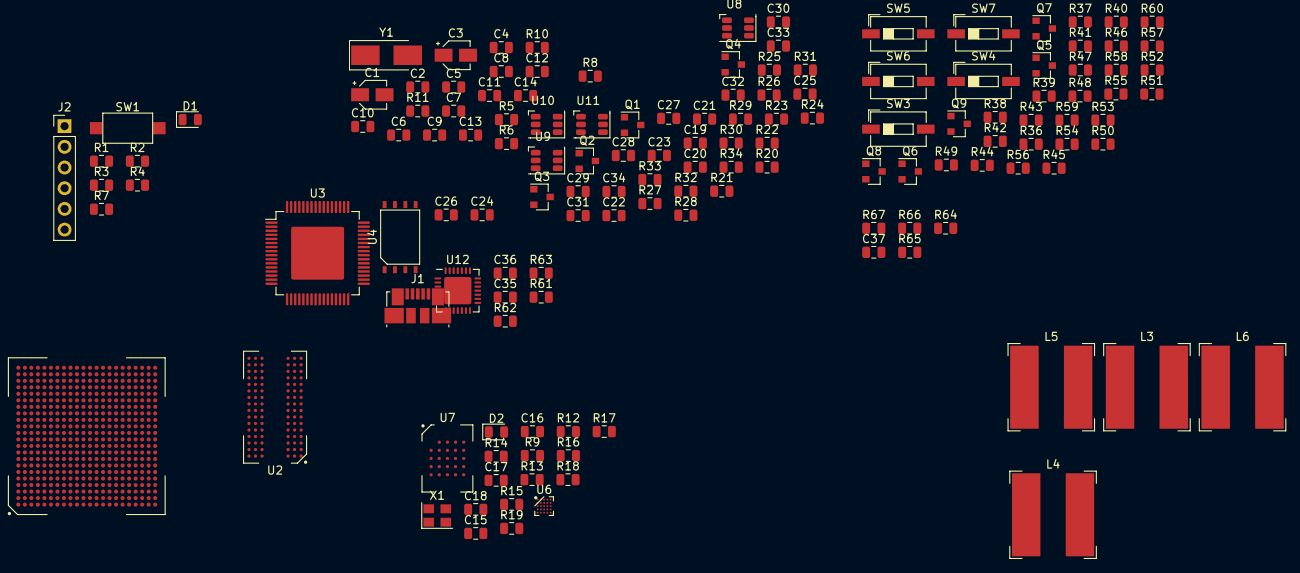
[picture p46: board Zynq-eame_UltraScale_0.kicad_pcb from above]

Board: 2 copper layers, 139 parts (0 on the bottom side), 155 nets, no tracks yet.

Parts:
C1, C3: 4.7uF; CP_Elec_3x5.3
C2, C5, C6, C9, C10, C11, C12, C13, C14, C15, C16, C17, C18, C23, C24, C25, C26, C36, C37: 100nF; C_0805_2012Metric
C4, C7: 27pF; C_0805_2012Metric
C8: 3.3uF; C_0805_2012Metric
C19, C20, C21, C22, C27, C28, C29, C30, C31, C32, C33, C34: 10uF; C_0805_2012Metric
C35: 4.7uF; C_0805_2012Metric
D1, D2: LED_ALT; LED_0805_2012Metric
J1: USB_B_Micro; USB_Micro-B_Molex_47346-0001
J2: Conn_01x06; PinHeader_1x06_P2.54mm_Vertical
L3, L4, L5, L6: 4.7uH; L_Bourns-SRN1060
Q1, Q2, Q3, Q4: MMBT3904; SOT-23
Q5, Q6, Q7, Q8, Q9: MMBF170; SOT-23
R1, R2, R4, R16, R19, R37, R39, R40, R41, R44, R45, R46, R49, R50, R52, R54, R55, R56, R58, R60: 4.7K; R_0805_2012Metric
R3, R7, R12, R13, R36, R42, R47, R51, R57, R65: 1K; R_0805_2012Metric
R5, R9, R10, R17, R22, R23, R24, R62: 10k; R_0805_2012Metric
R6: 2k2; R_0805_2012Metric
R8: 12k; R_0805_2012Metric
R11, R63: 1k; R_0805_2012Metric
R14: 820; R_0805_2012Metric
R15: 1300; R_0805_2012Metric
R18: 330; R_0805_2012Metric
R20, R21, R26, R38, R43, R48, R53, R59: 10K; R_0805_2012Metric
R25: 0R; R_0805_2012Metric
R27, R30, R32, R34: 100k; R_0805_2012Metric
R28: 75k; R_0805_2012Metric
R29: 56k; R_0805_2012Metric
R31: 33k; R_0805_2012Metric
R33: 20K; R_0805_2012Metric
R61: 4.7k; R_0805_2012Metric
R64: 300; R_0805_2012Metric
R66, R67: 240; R_0805_2012Metric
SW1: SW_Push; SW_SPST_CK_RS282G05A3
SW3, SW4, SW5, SW6, SW7: SW_SPST; SW_DIP_SPSTx01_Slide_6.7x4.1mm_W6.73mm_P2.54mm_LowProfile_J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
U1: XCZU2CG; SBVA484
U2: MT40A512M16; FBGA96_LY
U3: FT2232H; LQFP-64-1EP_10x10mm_P0.5mm_EP6.5x6.5mm
U4: 93C46; EIAJ_SOIC
U6: IP4856CX25; BGA-25_5x5_2.049999x2.049999mm
U7: MT25QU512ABB; BGA-25_5x5_6.0x8.0mm
U8, U9, U10, U11: TPS563201
U12: CP2102N-A01-GQFN28; QFN-28-1EP_5x5mm_P0.5mm_EP3.35x3.35mm
X1: ASE-33.333MHz; Oscillator_SMD_Abracon_ASE-4Pin_3.2x2.5mm
Y1: 12MHz; Crystal_SMD_5032-2Pin_5.0x3.2mm_HandSoldering

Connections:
+0V85: C30.1, C34.1, L6.2, Q2.1, R33.1, U1.F19, U1.H7, U1.H8, U1.H10, U1.H19, U1.J7, U1.J9, U1.J11, U1.K8, U1.K19, U1.L7, U1.L11, U1.M7, U1.M8, U1.N7, U1.N11, U1.N12, U1.N13, U1.N14, U1.N17, U1.P8, U1.P10, U1.P12, U1.P13, U1.P17, U1.R6, U1.R7, U1.R9, U1.R11, U1.R13, U1.R14, U1.R15, U1.R16, U1.T6, U1.T12, U1.T13, U1.T14, U1.T16, U1.T17
+1V2: C28.1, C32.1, L4.2, R20.2, R29.2, U1.AB18, U1.M14, U1.M15, U1.P19, U1.T20, U1.V16, U1.V21, U1.Y17, U1.Y22, U2.A1, U2.A2, U2.A8, U2.A9, U2.C1, U2.C9, U2.D2, U2.D8, U2.D9, U2.E3, U2.E8, U2.F1, U2.F2, U2.F8, U2.G1, U2.G9, U2.H1, U2.H9, U2.J2, U2.J8
+1V8: C8.1, C9.1, C10.1, C11.1, C12.1, C13.1, C14.1, C15.1, C17.1, C27.2, C31.2, L3.2, R18.1, R25.1, R27.1, R37.1, R39.1, R41.1, R44.1, R46.1, U1.A21, U1.AA5, U1.B3, U1.B8, U1.B19, U1.C4, U1.C11, U1.C16, U1.D14, U1.D19, U1.E7, U1.F10, U1.G3, U1.G13, U1.H16, U1.J6, U1.K2, U1.K5, U1.K6, U1.L6, U1.L13, U1.L14, U1.L16, U1.L17, U1.M6, U1.M12, U1.M16, U1.M17, U1.M20, U1.P4, U1.P6, U1.V6, U3.12, U3.37, U3.49, U3.64, U6.B3, U7.B4
+2V5: R64.1, R65.2, U2.B1, U2.R9
+3V3: C16.1, C18.2, C29.1, C33.1, J2.6, L5.2, R1.2, R2.2, R3.2, R4.2, R5.1, R9.1, R10.1, R11.2, R12.2, R16.2, R17.1, R19.1, R31.1, R64.2, U3.20, U3.31, U3.42, U3.50, U3.56, U4.6, U4.8, U6.A4, U6.C4, X1.4
/DDR/DDR_A0: U1.AA22, U2.P3
/DDR/DDR_A1: U1.AB20, U2.P7
/DDR/DDR_A2: U1.AB17, U2.R3
/DDR/DDR_A3: U1.AB19, U2.N7
/DDR/DDR_A4: U1.AB21, U2.N3
/DDR/DDR_A5: U1.AB16, U2.P8
/DDR/DDR_A6: U1.Y20, U2.P2
/DDR/DDR_A7: U1.Y19, U2.R8
/DDR/DDR_A8: U1.W17, U2.R2
/DDR/DDR_A9: U1.Y18, U2.R7
/DDR/DDR_A10: U1.Y21, U2.M3
/DDR/DDR_A11: U1.AA21, U2.T2
/DDR/DDR_A12: U1.AA18, U2.M7
/DDR/DDR_A13: U1.AA19, U2.T8
/DDR/DDR_A14: U1.AA17, U2.L2
/DDR/DDR_A15: U1.AA16, U2.M8
/DDR/DDR_A16: U1.Y16, U2.L8
/DDR/DDR_ACTN: U1.U15, U2.L3
/DDR/DDR_ALERTN: U1.T21, U2.P9
/DDR/DDR_BA0: U1.U17, U2.N2
/DDR/DDR_BA1: U1.V17, U2.N8
/DDR/DDR_BG0: U1.U16, U2.M2
/DDR/DDR_CK: U1.V20, U2.K7
/DDR/DDR_CKE: U1.U22, U2.K2
/DDR/DDR_CK_N: U1.W20, U2.K8
/DDR/DDR_CS: U1.V22, U2.L7
/DDR/DDR_D0: U1.AB11, U2.G2
/DDR/DDR_D1: U1.Y10, U2.F7
/DDR/DDR_D2: U1.AB10, U2.H3
/DDR/DDR_D3: U1.W10, U2.H7
/DDR/DDR_D4: U1.AA8, U2.H2
/DDR/DDR_D5: U1.Y8, U2.H8
/DDR/DDR_D6: U1.AB7, U2.J3
/DDR/DDR_D7: U1.AA7, U2.J7
/DDR/DDR_D8: U1.AA11, U2.A3
/DDR/DDR_D9: U1.Y11, U2.B8
/DDR/DDR_D10: U1.AA12, U2.C3
/DDR/DDR_D11: U1.AB12, U2.C7
/DDR/DDR_D12: U1.Y14, U2.C2
/DDR/DDR_D13: U1.AA14, U2.C8
/DDR/DDR_D14: U1.Y15, U2.D3
/DDR/DDR_D15: U1.AB15, U2.D7
/DDR/DDR_DM0: U1.AB9, U2.E7
/DDR/DDR_DM1: U1.AB14, U2.E2
/DDR/DDR_DQS_N0: U1.AA9, U2.F3
/DDR/DDR_DQS_N1: U1.AA13, U2.A7
/DDR/DDR_DQS_P0: U1.Y9, U2.G3
/DDR/DDR_DQS_P1: U1.Y13, U2.B7
/DDR/DDR_ODT: U1.W22, U2.K3
/DDR/DDR_PARITY: U1.U19, U2.T3
/DDR/DDR_RESETN: U1.T18, U2.P1
/MIO&REFERENCE/EECLK: R9.2, U3.62, U4.2
/MIO&REFERENCE/EECS: R10.2, U3.63, U4.1
/MIO&REFERENCE/EEDATA: R6.1, U3.61, U4.3
/MIO&REFERENCE/MIO8_TX: U1.V3, U12.25
/MIO&REFERENCE/MIO9_RX: U1.V5, U12.26
/MIO&REFERENCE/MIO_SD1_CLK: U1.C13, U6.C1
/MIO&REFERENCE/MIO_SD1_CMD: U1.A13, U6.D2
/MIO&REFERENCE/MIO_SD1_DAT0: U1.C12, U6.D1
/MIO&REFERENCE/MIO_SD1_DAT1: U1.B12, U6.E1
/MIO&REFERENCE/MIO_SD1_DAT2: U1.D13, U6.A1
/MIO&REFERENCE/MIO_SD1_DAT3: U1.A12, U6.B1
/MIO&REFERENCE/MIO_SD1_DIR_CMD: U1.D11, U6.A2
/MIO&REFERENCE/MIO_SD1_DIR_DAT0: U1.B10, U6.A3
/MIO&REFERENCE/PS_CLK: U1.H14, X1.3
/MIO&REFERENCE/PS_DONE: D1.2, R3.1, U1.L12
/MIO&REFERENCE/PS_ERROR: D2.2, R12.1, U1.K16
/MIO&REFERENCE/PS_INIT_B: R1.1, U1.K15
/MIO&REFERENCE/PS_POR_B: R17.2, U1.K12
/MIO&REFERENCE/PS_PROG_B: R2.1, U1.K14
/MIO&REFERENCE/PS_TCK: J2.4, U1.H13, U3.16
/MIO&REFERENCE/PS_TDI: J2.2, U1.H12, U3.17
/MIO&REFERENCE/PS_TDO: J2.3, U1.J13, U3.18
/MIO&REFERENCE/PS_TMS: J2.1, U1.J12, U3.19
/MIO&REFERENCE/QSPI_CLK: U1.U4, U7.B2
/MIO&REFERENCE/QSPI_CS: R18.2, U1.AA1, U7.C2
/MIO&REFERENCE/QSPI_DQ0: U1.U6, U7.D3
/MIO&REFERENCE/QSPI_DQ1: U1.W1, U7.D2
/MIO&REFERENCE/QSPI_DQ2: U1.V2, U7.C4
/MIO&REFERENCE/QSPI_DQ3: U1.U5, U7.D4
/MIO&REFERENCE/SRST_B: R4.1, SW1.1
/PINOUT/BT_1: R50.2, U1.F4
/PINOUT/BT_2: R52.2, U1.H3
/PINOUT/BT_3: R54.2, U1.G4
/PINOUT/BT_4: R56.2, U1.H4
/PINOUT/BT_5: R58.2, U1.G2
/PINOUT/LED_1: R36.2, U1.K3
/PINOUT/LED_2: R42.2, U1.K4
/PINOUT/LED_3: R47.2, U1.J2
/PINOUT/LED_4: R51.2, U1.J3
/PINOUT/LED_5: R57.2, U1.L3
/PINOUT/SW_1: R37.2, SW3.1, U1.H2
/PINOUT/SW_2: R39.2, SW4.1, U1.H5
/PINOUT/SW_3: R41.2, SW5.1, U1.J5
/PINOUT/SW_4: R44.2, SW6.1, U1.J1
/PINOUT/SW_5: R46.2, SW7.1, U1.K1
GND: C1.2, C2.1, C3.2, C4.2, C5.2, C6.2, C7.2, C8.2, C9.2, C10.2, C11.2, C12.2, C13.2, C14.2, C15.2, C16.2, C17.2, C18.1, C19.2, C20.1, C21.2, C22.2, C27.1, C28.2, C29.2, C30.2, C31.1, C32.2, C33.2, C34.2, C35.1, C36.2, C37.1, J1.5, J1.6, J2.5, Q1.2, Q2.2, Q3.2, Q4.2, Q5.2, Q6.2, Q7.2, Q8.2, Q9.2, R7.1, R8.2, R13.1, R15.2, R28.2, R30.1, R32.2, R34.2, R38.2, R43.2, R48.2, R50.1, R52.1, R53.2, R54.1, R56.1, R58.1, R59.2, R62.2, R65.1, R66.2, R67.2, SW1.2, SW3.2, SW4.2, SW5.2, SW6.2, SW7.2, U1.A1, U1.A5, U1.A10, U1.A15, U1.A18, U1.A22, U1.AA10, U1.AA15, U1.AA20, U1.AB1, U1.AB3, U1.AB8, U1.AB13, U1.AB22, U1.B13, U1.B20, U1.C1, U1.C6, U1.C18, U1.C21, U1.C22, U1.D4, U1.D9, U1.D20, U1.E2, U1.E12, U1.E17, U1.E18, U1.E21, U1.E22, U1.F5, U1.F15, U1.F20, U1.G8, U1.G18, U1.G21, U1.G22, U1.H1, U1.H6, U1.H9, U1.H11, U1.H17, U1.H20, U1.J4, U1.J8, U1.J10, U1.J14, U1.J18, U1.J21, U1.J22, U1.K7, U1.K11, U1.K17, U1.K20, U1.L5, U1.L8, U1.L15, U1.L18, U1.L21, U1.L22, U1.M3, U1.M11, U1.M13, U1.M18, U1.M19, U1.N1, U1.N6, U1.N8, U1.N15, U1.N16, U1.N20, U1.N21, U1.N22, U1.P7, U1.P9, U1.P11, U1.P14, U1.R2, U1.R8, U1.R10, U1.R12, U1.R17, U1.R22, U1.T5, U1.T11, U1.T15, U1.U3, U1.U8, U1.U13, U1.U18, U1.V1, U1.V11, U1.W4, U1.W9, U1.W14, U1.W19, U1.Y2, U1.Y7, U1.Y12, U2.B2, U2.B3, U2.B9, U2.D1, U2.E1, U2.E9, U2.G7, U2.G8, U2.J1, U2.J9, U2.K1, U2.K9, U2.L1, U2.L9, U2.M9, U2.N1, U2.N9, U2.R1, U2.T1, U2.T9, U3.1, U3.5, U3.10, U3.11, U3.13, U3.15, U3.25, U3.35, U3.47, U3.51, U4.5, U4.7, U6.C3, U7.B3, U8.1, U9.1, U10.1, U11.1, U12.3, U12.29, X1.2
unnamed: C1.1, C5.1, U3.9
unnamed: C2.2, J1.1
unnamed: C3.1, C6.1, U3.4
unnamed: C4.1, U3.2, Y1.1
unnamed: C7.1, U3.3, Y1.2
unnamed: C23.1, U11.6
unnamed: C23.2, L6.1, U11.2
unnamed: C24.1, L3.1, U8.2
unnamed: C24.2, U8.6
unnamed: C25.1, L4.1, U9.2
unnamed: C25.2, U9.6
unnamed: C26.1, L5.1, U10.2
unnamed: C26.2, U10.6
unnamed: C35.2, R61.2, U12.7
unnamed: C36.1, R63.1, U12.6
unnamed: C37.2, U2.M1
unnamed: D1.1, R7.2
unnamed: D2.1, R13.2
unnamed: J1.2, U3.7
unnamed: J1.3, U3.8
unnamed: Q1.1, R20.1
unnamed: Q1.3, Q4.1, R21.1
unnamed: Q2.3, Q3.1, R22.2
unnamed: Q3.3, R24.2, U8.5
unnamed: Q4.3, R26.1, U10.5
unnamed: Q5.1, R36.1, R38.1
unnamed: Q5.3, R40.2
unnamed: Q6.1, R42.1, R43.1
unnamed: Q6.3, R45.2
unnamed: Q7.1, R47.1, R48.1
unnamed: Q7.3, R49.2
unnamed: Q8.1, R51.1, R53.1
unnamed: Q8.3, R55.2
unnamed: Q9.1, R57.1, R59.1
unnamed: Q9.3, R60.2
unnamed: R5.2, R6.2, U4.4
unnamed: R8.1, U3.6
unnamed: R11.1, U3.14
unnamed: R14.2, R15.1
unnamed: R16.1, U6.C2
unnamed: R19.2, X1.1
unnamed: R23.1, U11.5
unnamed: R25.2, U9.5
unnamed: R27.2, R28.1, U8.4
unnamed: R29.1, R30.2, U9.4
unnamed: R31.2, R32.1, U10.4
unnamed: R33.2, R34.1, U11.4
unnamed: R61.1, R62.1, U12.8
unnamed: R63.2, U12.9
unnamed: R66.1, U2.F9
unnamed: R67.1, U1.T19
unnamed: U7.A2, U7.A3, U7.A4, U7.A5, U7.B1, U7.B5, U7.C1, U7.C3, U7.C5, U7.D1, U7.D5, U7.E1, U7.E2, U7.E3, U7.E5
VIN: C19.1, C20.2, C21.1, C22.1, R21.2, R22.1, R23.2, R24.1, R26.2, U8.3, U9.3, U10.3, U11.3

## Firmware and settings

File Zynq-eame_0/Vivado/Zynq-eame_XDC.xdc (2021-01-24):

#Zynq-eame 0
#soceame.wordpress.com

#HDMI

#set_property -dict { PACKAGE_PIN C20    IOSTANDARD LVCMOS33 } [get_ports HPD_A]; # HPD_A
#set_property -dict { PACKAGE_PIN B20    IOSTANDARD LVCMOS33 } [get_ports CEC_A]; # CEC_A
#set_property -dict { PACKAGE_PIN B19    IOSTANDARD LVCMOS33 } [get_ports HDMI_CLK+]; # HDMI_CLK+
#set_property -dict { PACKAGE_PIN A20    IOSTANDARD LVCMOS33 } [get_ports HDMI_CLK-]; # HDMI_CLK-
#set_property -dict { PACKAGE_PIN E17    IOSTANDARD LVCMOS33 } [get_ports HDMI_D0+]; # HDMI_D0+
#set_property -dict { PACKAGE_PIN D18    IOSTANDARD LVCMOS33 } [get_ports HDMI_D0-]; # HDMI_D0-
#set_property -dict { PACKAGE_PIN D19    IOSTANDARD LVCMOS33 } [get_ports HDMI_D1+]; # HDMI_D1+
#set_property -dict { PACKAGE_PIN D20    IOSTANDARD LVCMOS33 } [get_ports HDMI_D1-]; # HDMI_D1-
#set_property -dict { PACKAGE_PIN E18    IOSTANDARD LVCMOS33 } [get_ports HDMI_D2+]; # HDMI_D2+
#set_property -dict { PACKAGE_PIN E19    IOSTANDARD LVCMOS33 } [get_ports HDMI_D2-]; # HDMI_D2-

#Buttons

#set_property -dict { PACKAGE_PIN H18    IOSTANDARD LVCMOS33 } [get_ports BT_1]; # button 1
#set_property -dict { PACKAGE_PIN F19    IOSTANDARD LVCMOS33 } [get_ports BT_2]; # button 2
#set_property -dict { PACKAGE_PIN F20    IOSTANDARD LVCMOS33 } [get_ports BT_3]; # button 3
#set_property -dict { PACKAGE_PIN G17    IOSTANDARD LVCMOS33 } [get_ports BT_4]; # button 4
#set_property -dict { PACKAGE_PIN G18    IOSTANDARD LVCMOS33 } [get_ports BT_5]; # button 5

#Leds

#set_property -dict { PACKAGE_PIN L20    IOSTANDARD LVCMOS33 } [get_ports LED_1]; # Led 1
#set_property -dict { PACKAGE_PIN K19    IOSTANDARD LVCMOS33 } [get_ports LED_2]; # Led 2
#set_property -dict { PACKAGE_PIN J19    IOSTANDARD LVCMOS33 } [get_ports LED_3]; # Led 3
#set_property -dict { PACKAGE_PIN L16    IOSTANDARD LVCMOS33 } [get_ports LED_4]; # Led 4
#set_property -dict { PACKAGE_PIN L17    IOSTANDARD LVCMOS33 } [get_ports LED_5]; # Led 5

#Switchs

#set_property -dict { PACKAGE_PIN K17    IOSTANDARD LVCMOS33 } [get_ports SW_1]; # Switch 1
#set_property -dict { PACKAGE_PIN K18    IOSTANDARD LVCMOS33 } [get_ports SW_2]; # Switch 2
#set_property -dict { PACKAGE_PIN H16    IOSTANDARD LVCMOS33 } [get_ports SW_3]; # Switch 3
#set_property -dict { PACKAGE_PIN H17    IOSTANDARD LVCMOS33 } [get_ports SW_4]; # Switch 4
#set_property -dict { PACKAGE_PIN J18    IOSTANDARD LVCMOS33 } [get_ports SW_5]; # Switch 5

#SD

#set_property -dict { PACKAGE_PIN D14    IOSTANDARD LVCMOS33 } [get_ports SD_CLK]; # SD_CLK
#set_property -dict { PACKAGE_PIN C17    IOSTANDARD LVCMOS33 } [get_ports SD_CMD]; # SD_CMD
#set_property -dict { PACKAGE_PIN E12    IOSTANDARD LVCMOS33 } [get_ports SD_D0]; # SD_D0
#set_property -dict { PACKAGE_PIN A9     IOSTANDARD LVCMOS33 } [get_ports SD_D1]; # SD_D1
#set_property -dict { PACKAGE_PIN F13    IOSTANDARD LVCMOS33 } [get_ports SD_D2]; # SD_D2
#set_property -dict { PACKAGE_PIN B15    IOSTANDARD LVCMOS33 } [get_ports SD_D3]; # SD_D3

#USB RX - TX

#set_property -dict { PACKAGE_PIN A16    IOSTANDARD LVCMOS33 } [get_ports RX]; # RX
#set_property -dict { PACKAGE_PIN F15    IOSTANDARD LVCMOS33 } [get_ports TX]; # TX

#QUAD-SPI FLASH MEMORY

#set_property -dict { PACKAGE_PIN A7    IOSTANDARD LVCMOS33 } [get_ports MIO1]; # CS#
#set_property -dict { PACKAGE_PIN B8    IOSTANDARD LVCMOS33 } [get_ports MIO2]; # IO0
#set_property -dict { PACKAGE_PIN D6    IOSTANDARD LVCMOS33 } [get_ports MIO3]; # IO1
#set_property -dict { PACKAGE_PIN B7    IOSTANDARD LVCMOS33 } [get_ports MIO4]; # IO2
#set_property -dict { PACKAGE_PIN A6    IOSTANDARD LVCMOS33 } [get_ports MIO5]; # IO3
#set_property -dict { PACKAGE_PIN A5    IOSTANDARD LVCMOS33 } [get_ports MIO6]; # SCK


# Pin Bank 34
# JP1
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

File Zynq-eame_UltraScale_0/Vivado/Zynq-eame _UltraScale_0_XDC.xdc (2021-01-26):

#Zynq-eame UltraScale 0
#soceame.wordpress.com
# GitHub: https://github.com/DRubioG/Zynq-eame/tree/main/Zynq-eame_UltraScale_0

#Buttons

#set_property -dict { PACKAGE_PIN F4    IOSTANDARD LVCMOS18 } [get_ports BT_1]; # button 1
#set_property -dict { PACKAGE_PIN H3    IOSTANDARD LVCMOS18 } [get_ports BT_2]; # button 2
#set_property -dict { PACKAGE_PIN G4    IOSTANDARD LVCMOS18 } [get_ports BT_3]; # button 3
#set_property -dict { PACKAGE_PIN H4    IOSTANDARD LVCMOS18 } [get_ports BT_4]; # button 4
#set_property -dict { PACKAGE_PIN G2    IOSTANDARD LVCMOS18 } [get_ports BT_5]; # button 5

#Leds

#set_property -dict { PACKAGE_PIN K3    IOSTANDARD LVCMOS18 } [get_ports LED_1]; # Led 1
#set_property -dict { PACKAGE_PIN K4    IOSTANDARD LVCMOS18 } [get_ports LED_2]; # Led 2
#set_property -dict { PACKAGE_PIN J2    IOSTANDARD LVCMOS18 } [get_ports LED_3]; # Led 3
#set_property -dict { PACKAGE_PIN J3    IOSTANDARD LVCMOS18 } [get_ports LED_4]; # Led 4
#set_property -dict { PACKAGE_PIN L3    IOSTANDARD LVCMOS18 } [get_ports LED_5]; # Led 5

#Switchs

#set_property -dict { PACKAGE_PIN H2    IOSTANDARD LVCMOS18 } [get_ports SW_1]; # Switch 1
#set_property -dict { PACKAGE_PIN H5    IOSTANDARD LVCMOS18 } [get_ports SW_2]; # Switch 2
#set_property -dict { PACKAGE_PIN J5    IOSTANDARD LVCMOS18 } [get_ports SW_3]; # Switch 3
#set_property -dict { PACKAGE_PIN J1    IOSTANDARD LVCMOS18 } [get_ports SW_4]; # Switch 4
#set_property -dict { PACKAGE_PIN K1    IOSTANDARD LVCMOS18 } [get_ports SW_5]; # Switch 5
